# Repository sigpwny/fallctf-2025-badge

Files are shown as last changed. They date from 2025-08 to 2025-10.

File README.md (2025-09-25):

# FallCTF 2025 badge software and hardware

## Flags

Boot flag: `fallctf{s1gpwny_m4k3s_h4rdwar3!}`
game high score flag: `fallctf{w1z4rd_0f_st4rdust}`

## Software

See [board-setup/](board-setup/README.md) for flashing firmware on to the badge. See [dev/](dev/README.md) for the user code.

## Hardware

See [hardware/](hardware/README.md) for hardware design information.

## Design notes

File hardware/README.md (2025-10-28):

# Hardware

I recommend using Github's outline feature to navigate this document.

## Versioning

The PCB folder contains several versions of schematics. v0.1 through v0.3 were the prototype versions. v1.0 was used as the final badge design.

## Microcontroller

The badge has an ESP32-S2-SOLO-2-N4 module. This module features an ESP32-S2 SoC with 4MB of flash and internal antenna for 2.4Ghz Wi-Fi (no bluetooth).

The datasheet for the ESP32-S2-SOLO-2-N4 module is available [here](https://www.espressif.com/sites/default/files/documentation/esp32-s2-solo-2_esp32-s2-solo-2u_datasheet_en.pdf). See [here](https://www.espressif.com/sites/default/files/documentation/esp32-s2_datasheet_en.pdf) for the ESP32-S2 series documentation and [here](https://www.espressif.com/sites/default/files/documentation/esp32-s2_technical_reference_manual_en.pdf) for the ESP32-S2 technical reference manual.

### Boot modes

GPIO 46 (pin 16) is pulled low to avoid invalid configurations in boot pins. GPIO 0 (pin 27) is connected to the "B" pushbutton to allow switching between SPI (flash) boot and download (USB) boot. By default, it is pulled up, which selects SPI boot.

## Battery

The battery is a 400mAH 3.7V lithium-ion polymer battery.

## Peripherals

The FallCTF 2025 comes with a number of peripherals accessible from the ESP32 module via software. This is designed to be a comprehensive list for software developers working on the badge.

GPIO numbers are given for the ESP32 module. The relationship between pin numbers and IO port numbers are given in Table 3 on page 11 of the ESP32-S2-SOLO-2 datasheet.

### Overview

The following peripherals are available:
- USB (serial)
- two push buttons
- battery charge monitor
- SAO header
- buzzer
- joystick
- current sensor
- accelerometer
- display

### USB

USB D- is connected to GPIO 19 and D+ to GPIO 20 as required for "download boot", which is used to program the ESP32 over USB.

### Push buttons

"A" button is connected to GPIO 13 and "B" is connected to GPIO 0. Both buttons are pulled up by a 10K resistor and shorted to ground when depressed.

### Battery charge monitor

The battery is connected, through a pair of 100K resistors acting as a voltage divider, to GPIO 8. This allows for software to detect the battery charge via an ADC.

### SAO header

The SAO header shares an I2C connection with the accelerometer. SCL connected to GPIO 21 and SDA to GPIO 33. There are two SAO GPIO pins connected to GPIO 11 and GPIO 12.

### Buzzer

Both ends of the passive piezo buzzer are connected to the ESP32 through 220 Ohm resistors. One end is connected to GPIO 3 and the other to GPIO 9. We recommend grounding one of the pins and using the other as the PWM signal source.

### Joystick

The two axes of the joystick are connected to GPIO 4 and 5. The range is around from 0.8V to 1.4V. This varies by 2%-5% across devices.

The joystick has an internal variable resistance of 5K. One end is connected to an 8.2K resistor and the other end to a 820 Ohm resistor.

The exact part is [YTL YA13-FL7.4-B5Ka(45-10)-R-Y06](https://www.lcsc.com/datasheet/C37323742.pdf).

### Current sensor

There is a INA199A1DCKR ([datasheet](https://www.ti.com/lit/ds/symlink/ina199.pdf?ts=1758695550045)) connected to the 3.3V bus acting as a current sensor. It has a gain of 50 V/V. The output voltage is connected to GPIO 10. The current sensing resistor is 0.1 Ohms. To measure the operating current in Amps, use the formula `A = V / (I_R * G)`, where `A` is the operating current, `V` is the measured voltage in volts, `I_R` is the current sensing resistance (0.1 Ohms), and `G` is the gain (50 V/V).

From our testing, the current sensor is not very reliable and fluctuates wildly during use, reporting readings between 50% and 300%.

### Accelerometer

The STK8321 accelerometer ([datasheet](https://uploadcdn.oneyac.com/attachments/files/brand_pdf/sensortek/STK8321.pdf)) is attached to the same I2C lines as the SAO header (GPIO 21 and GPIO 33). The accelerometer's two interrupt pins are connected to GPIO 37 and GPIO 38. The slave address select pin is connected to GPIO 36. By default, this pin is pulled low, which selects the I2C address 0x0F. The chip supports a max I2C frequency of 400kHz.

Example initialization process:
- write 0xB6 to 0x14 (SWRST) to reset the chip
- write 0x03 to 0x0F (RANGESEL) to set the range to +/- 2g (this can be changed to 0x05 for +/- 4g or 0x08 for +/- 8g)
- write 0x0B to 0x10 (BWSEL) to set the bandwidth to 62.5Hz (this can be changed for different bandwidths)

For an example of code used to drive the accelerometer, see dev/accelerometer.py

### Display

The display is a 1.8" 128x160 color TFT LCD display with a ST7735S controller, sourced [from BuyDisplay](https://www.buydisplay.com/128x160-1-8-inch-color-tft-lcd-display-with-st7735-controller-spi). The controller datasheet is available [here](https://www.buydisplay.com/download/ic/ST7735S.pdf).

The following pins are connected:
- CS: GPIO 17
- RESET: GPIO 18
- DC: GPIO 7
- MOSI: GPIO 16
- SCK: GPIO 15
- LCD_LED: GPIO 41

The CS (chip select) and RESET pins are pulled high by default by the PCB. The DC and MOSI pins allow data and commands to be transmitted to the display controller. The SCK determines the clock speed. The datasheet specifies a max clock speed of 15Mhz, but we have found through testing that it supports a clock rate as high as 90Mhz (although values above 61Mhz do not appear to have any differences). In the final badge design, we used 40Mhz.

The LCD_LED pin is connected to a MOSFET which switches the backlight on and off. This pin can be driven with PWM to adjust the brightness of the backlight. We have found that a duty cycle between 20% and 40% offers a good visual experience.

## Prototype pictures

### v0.1

TODO: add pictures

### v0.2

TODO: add pictures

### v0.3

TODO: add pictures

### v1.0

TODO: add pictures

## Design process and challenges

### Lessons learned

Here are some of the most important lessons I learned during the hardware design process:
- Use a circuit simulator (such as [falstad](https://www.falstad.com/circuit/circuitjs.html)). This is great especially if you don't have a solid grasp of basic electronics (like me at the start of this project). This allows you to catch basic mistakes such as flipped MOSFETs or incorrect resistor values.
- Design PCBs with plenty of room. In the prototyping stage, there's no need to squeeze everything together. Space out the traces to make reworking easier. This also makes it easier to debug and test the board.
- Order small batches. I ordered 10-15 boards at a time, which was unnecessary and wasteful. Ordering 5 boards at a time is sufficient for prototyping.

### Electrical problems

- USB shell
    - In v0.1, I connected the shell to ground through a 1M resistor. This was a mistake and removed in v0.2. The shell should be connected directly to ground.
- current limits
    - In v0.3, the LDO was only rated for 300mA, which is not enough to power the ESP32 at full Wi-Fi power. This was fixed in v1.0 by using a 500mA LDO.
- MOSFET direction
    - In v0.1, I was using the P-channel MOSFET in the wrong direction (swapped source and drain). This was fixed in v0.2, although this iteration had other problems (see below).
- MOSFET body diode
    - In v0.3, the body diode on the Q1 MOSFET allowed the 5V to inadvertently flow back to the battery, charging it. This was a problem as this spiked the current drawn from the USB port, causing it to shut off. This was fixed in v1.0 by using a second MOSFET (Q5). I made this mistake because I forgot about the body diode in a MOSFET and mistakenly believed that tying gate and source together would turn it off even if the drain was at a higher voltage than the source.
- swapped display backlight pins
    - In v0.2, I swapped the anode and cathode of the backlight LED. This was fixed in v0.3.

### Physical layout

- ESP32 module does not need to stick out of the board. This was recommended by the design, but some testing revealed that the antenna performance was not significantly affected by being surrounded by PCB material. The protruding design makes the badge more fragile and prone to damage.
- Switches not stick out too far from the edge of the board. Sometimes the 3D model can be misleading. Always check the physical size with the datasheet.
- In general, confirm the physical size of large parts to make sure they do not interfere with each other

### Part selection

Here is my general process for part selection:
- Choose parts that are commonly used and have good documentation. Avoid obscure parts that may be hard to source or have poor documentation.
- Prefer JLCPCB's basic parts, as they incur lower production costs.
- If there is a part you like that is too expensive, look for alternatives with the same specifications on multiple websites. Generally, most parts have "generic" versions that are significantly cheaper.

### JLCPCB PCBA capabilities

Keep in mind manufacturer's PCBA capabilities when designing the PCB, specifically when setting up the design rules. See [JLCPCB's capabilities](https://jlcpcb.com/capabilities/pcb-capabilities). In particular, the page on [extra fees](https://jlcpcb.com/help/article/in-what-cases-will-there-be-charged-extra) states that the via inner hole size must be at least 0.3mm and the via outer diameter must be at least 0.4mm to qualify for no extra fees (note: the via hole size can be at least 0.2mm if the via diameter is at least 0.45mm).

### Lanyards

Lanyards weren't ordered in time for the competition. We ordered it the Monday before the competition (6 days prior), which was way too late. In future, we should order lanyards at least 3 weeks in advance.

### Lack of RAM

This is more of a software problem, but the underlying cause was hardware. We kept running out of RAM, as micropython by itself is very RAM-hungry. On top of that, the ESP Wi-Fi stack requires significant amount of memory as well. Adding to the problem is the fact that micropython runs as a task in ESP-IDF (which is based on FreeRTOS). This means that the micropython heap is separate from ESP-IDF's heap, and memory fragmentation can occur in both heaps. The solution was to freeze as much code as possible into the firmware, which reduces the amount of RAM needed at runtime. However, in future designs, we could use one of the ESP32 modules with embedded PSRAM (or even use a ESP32 SoC directly with external PSRAM).

### Improvements for future designs

- Separate user controllable (blue?) LED. No need for a power LED.
- Increase joystick voltage divider R39 and R40 to around 10K

### Software is hard

My biggest advice regarding software is to start earlier. I would recommend starting in early spring. The idea should be concretized by the end of spring so that work can begin over the summer. I think one of the biggest issues with the FallCTF 2025 badge was that the main software idea was not finalized until August, which left very little time for development and testing.

## Final hardware design

### ESP32 module

Most of the design is pretty straightforward. There wasn't anything here that significantly differed from the recommended design in the datasheet.

### USB

We use several diodes for surge and ESD protection on the USB data and power lines. CC1 and CC2 are connected to ground through 5.1K resistors to indicate to the host that this is a USB 2.0 device, which allows it to draw up to 500mA from the host. The shell is connected directly to ground.

### Power regulation

This was by far the most complicated part of the design. The design went through several iterations before arriving at the current version, which uses two P-channel MOSFETs to switch between USB power and battery power. Notice that the Q1 MOSFET in the v1.0 schematic is actually "flipped" upside down: the source is at the bottom and the drain is at the top. There are three cases to consider:

- When both the USB and battery are connected. The 5V on the USB line causes the gate and source of Q1 to be at the same voltage (minus a small drop from the Schottky diode), so Q1 is turned off. This prevents current from flowing back to the battery, as there is separate dedicated circuitry to charge the battery. The 5V flows downstream to the LDO to power the rest of the badge.
- When only the USB is connected. The same logic as above applies, and the badge is powered from the USB line.
- When only the battery is connected. This is where it gets interesting. Depending on the state of SW1, the gate of Q5 is either tied to ground or to VBAT. If it is tied to ground, then Q5 is turned off and no current can flow past it. If it is tied to VBAT (which is also Q5's source), then Q5 is turned on and current can flow through Q5. From there, the current flows through the body diode of Q1 (which is oriented in the correct direction to allow current flow) and into the LDO to power the badge. The Schottky diode (D4) prevents current from flowing back to the USB line.

The Schottky diode can be used because the drop from 5V to 3.3V is large enough that the small drop across the diode (typically around 0.3V) does not matter. The resistors on the gate of each MOSFET are to prevent inrush current from damaging the MOSFET (I'm not sure if this is actually necessary, but it doesn't hurt). The pull-down resistor R2 is not necessary and is a remnant from an earlier design iteration.

The ME6211C33M5G 3.3V LDO I chose can handle up to 500mA of current, which is the recommended amount for the ESP32. In previous iterations, the LDO could only handle 300mA, which was not enough to power the badge when transmitting at full Wi-Fi power.

### Power indicator LED

Tuning the resistor on this LED was surprisingly tricky. I went from 680 -> 8.2K -> 13K. If the [datasheet](https://www.lcsc.com/datasheet/C2297.pdf) is to be trusted, the 13K resistor should result in a current of around 75uA, which is extremly dim (less than 2% of the intensity at 5mA, which is between 175 and 430 mcd with a 120 degree viewing angle).

### Battery charging

I used the TP4054 ([datasheet](https://media.digikey.com/pdf/Data%20Sheets/UTD%20Semi%20PDFs/TP4054.pdf)) for battery charge control. I used a 4.7K resistor to program the max charging current to 200mA, but that may have been too conservative. A better approach would be to allow the MCU to program this value (even something as simple as selecting between a "fast" and "slow" charge would have been better). There is some slightly more complicated circuitry to control the green and red charging LEDs, but those are straight from the datasheet. The resistor values have been tuned to reduce the brightness (since the LEDs are quite efficient).

### Buttons

Nothing special here. Standard 10K pull-up resistors.

### Joystick

Connected the joystick in series with a 8.2K on one side and a 820 Ohm resistor on the other side to offset the voltage divider so it sits nicely within the ESP32's ADC range (2.5V). This could have been improved by increasing the resistance slightly so that it fits in the `ADC_ATTEN_DB_6` range (which is 0V-1.3V). Currently the max is around 1.4V, which is slightly out of this narrower range.

### Accelerometer

Recommended design from the datasheet. Connecting the interrupts to the ESP32 was a nice feature, but unused.

### Current sensing

Fluctuates wildly. I'm not sure if the actual current is really so unstable or if I could have chose a better sensing resistor or amplifier.

### Buzzer

I connected both ends to the ESP32 through 220 Ohm resistors for greater flexibility in control. This allows the buzzer to be driven in a push-pull configuration, which would be twice as loud as driving it in a single-ended configuration. However, the buzzer is quite loud even when driven in a single-ended configuration, so this was unnecessary.

### Display

Besides connecting a N-channel MOSFET to be able to vary the backlight, everything else was straight from the datasheet.

## Costs

Here are the main costs associated with developing the badge for FallCTF 2025. We ended up ordering 300 badges in the final order.

- prototypes
    - over three revisions of prototypes, we spent: $709.52
    - 3.76 + 60.00 + 73.99 + 43.68 + 20.88 + 16.30 + 162.02 + 26.74 + 56.96 + 5.98 + 180.66 + 17.45 + 41.10
- PCBA
    - total: $1782.33
    - includes $70.02 part preorder
    - cost breakdown:
        - MERCHANDISE TOTAL: $900.81
        - SHIPPING CHARGE: $226.86
        - Customs duties & taxes: $525.72
        - DISCOUNT: -$15.00
        - SALES TAX: $73.92
        - ORDER TOTAL: $1712.31
    - pcb cost: $173.10
    - assembly cost: $727.71 ($366.59 for components)
        - does not include ESP32, which we got for free
- other final badge parts
    - batteries: $453.88
        - supplier: [General Electronics Technology Co., Ltd.](https://geb.en.alibaba.com/index.html?spm=a2700.details.0.0.346c748eiMNOtQ&from=detail&productId=1600518355723)
    - displays: $1008.65 (including $281.56 duty)
- lanyards: $253
- badge cases: $260 (3d printed in our school's print farm)
 
Total costs: $4600

## Gallery

### PCB prototypes

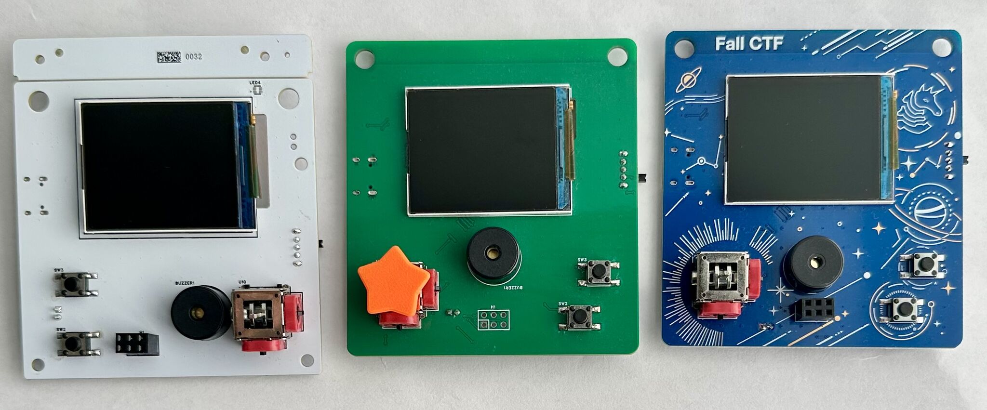
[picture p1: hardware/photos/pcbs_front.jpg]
The front of three prototype boards


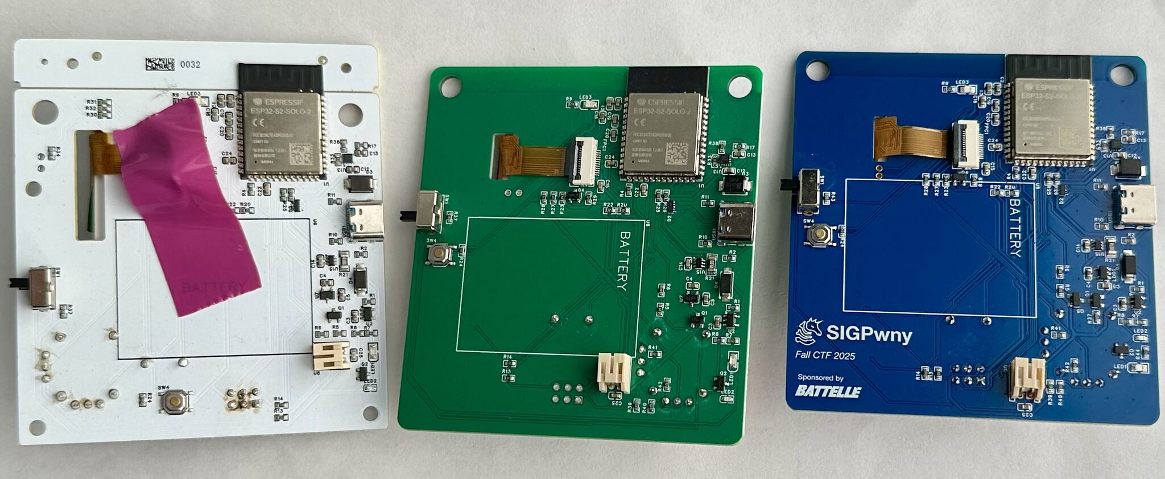
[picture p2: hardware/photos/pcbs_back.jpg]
The back of three prototype boards


### Case prototypes

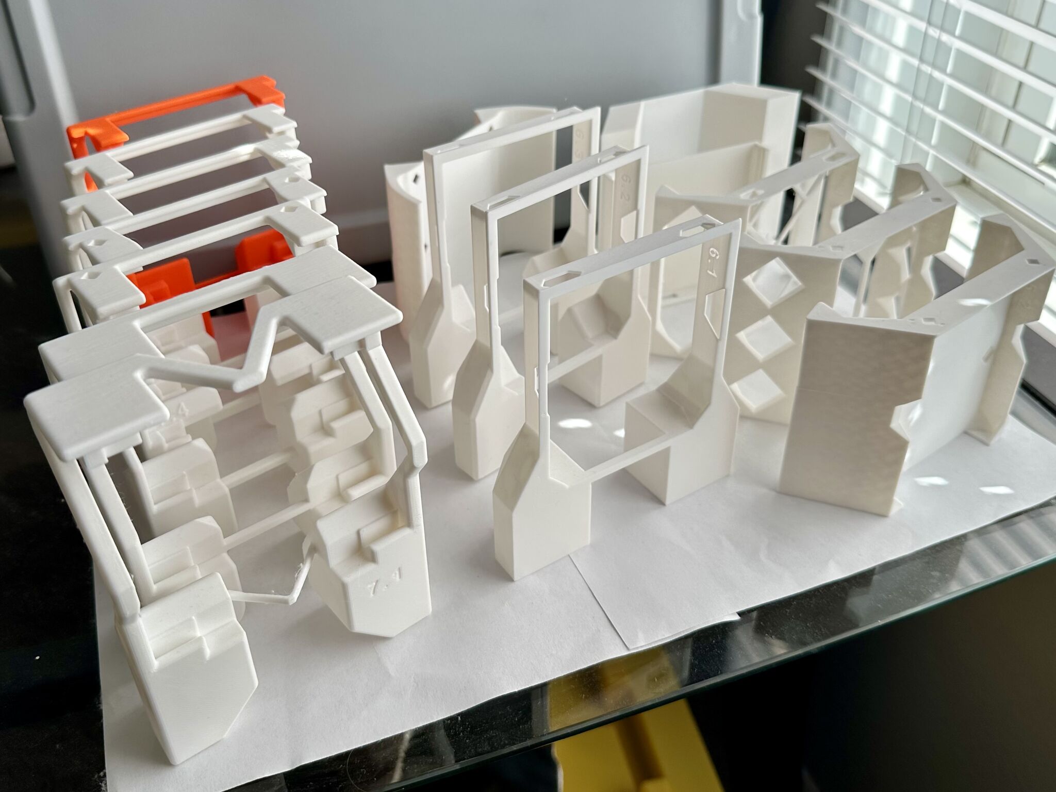
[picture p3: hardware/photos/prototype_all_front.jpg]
Front view of more than a dozen 3D printed prototype cases


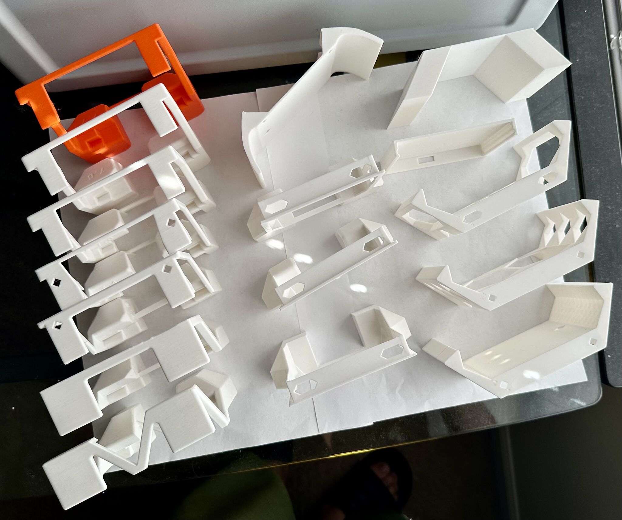
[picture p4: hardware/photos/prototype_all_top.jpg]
Top view of more than a dozen 3D printed prototype cases


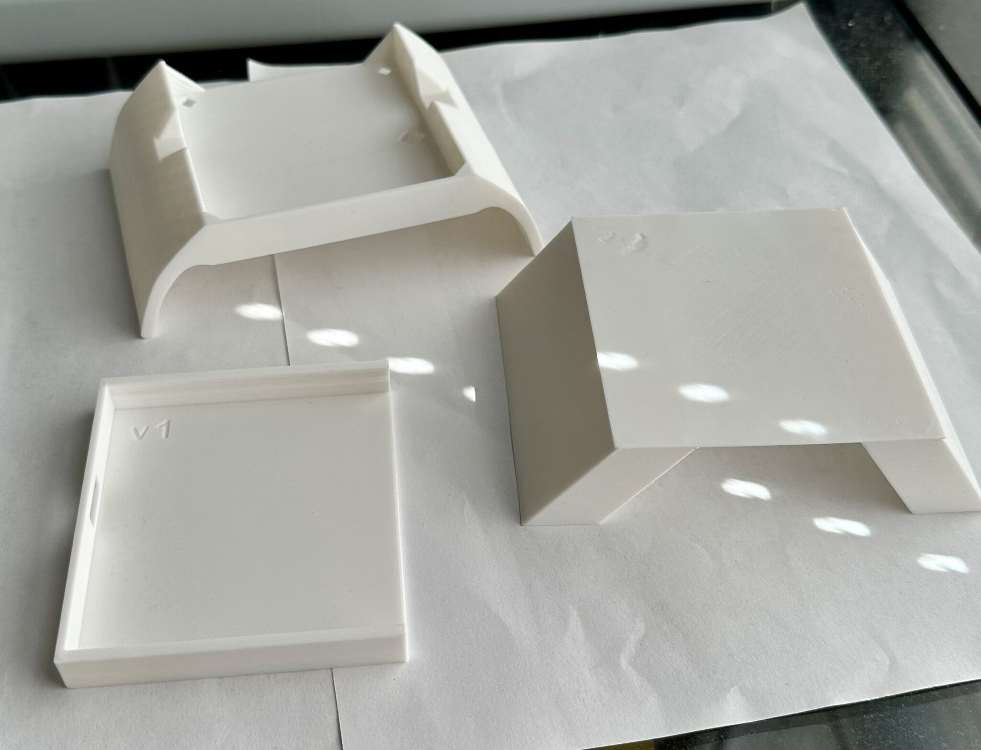
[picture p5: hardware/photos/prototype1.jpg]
Three early stage prototypes, simple geometric shapes


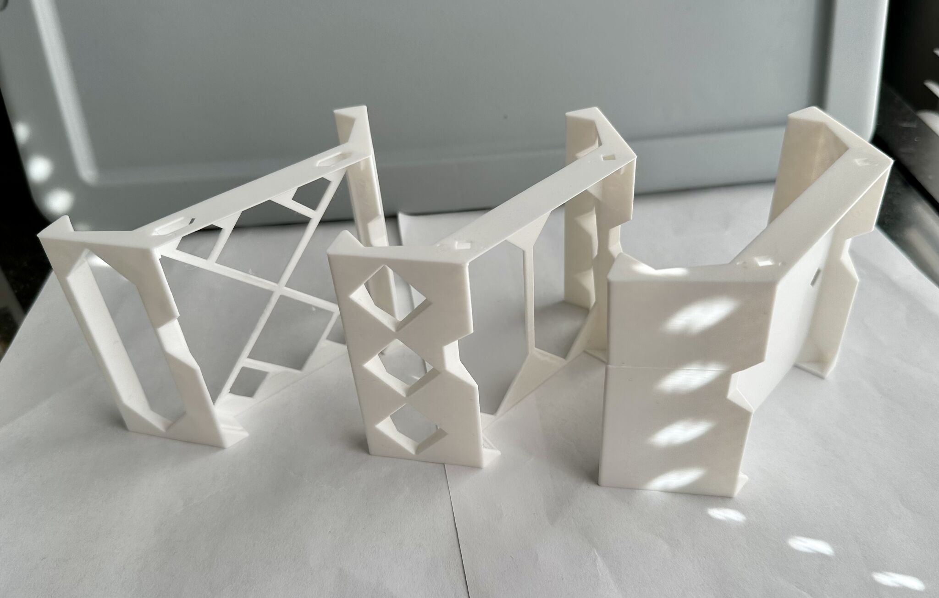
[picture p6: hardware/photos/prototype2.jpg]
Three more prototypes with more holes for cost reduction


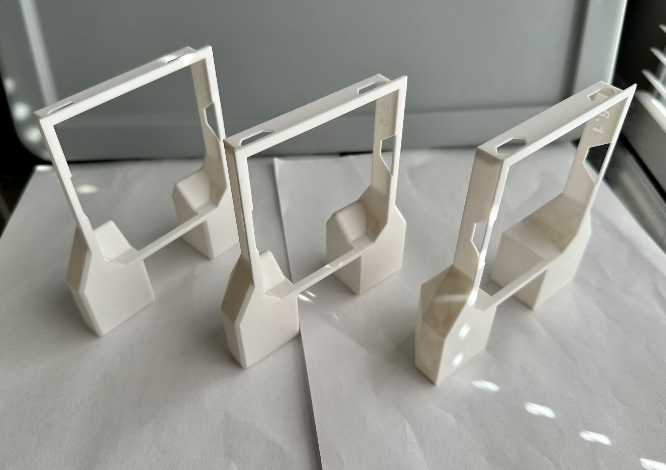
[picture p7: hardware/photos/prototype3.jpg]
Three more prototypes with handles for easier grip


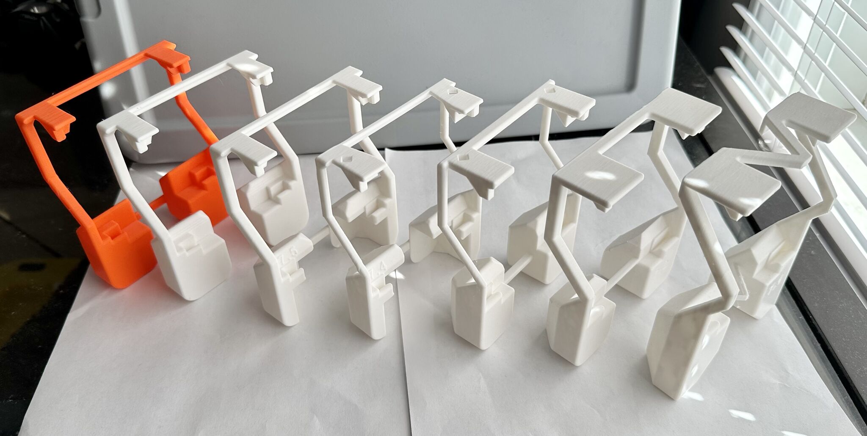
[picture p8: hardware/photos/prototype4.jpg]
Final series of seven prototypes with overall boxy look


### Final badge

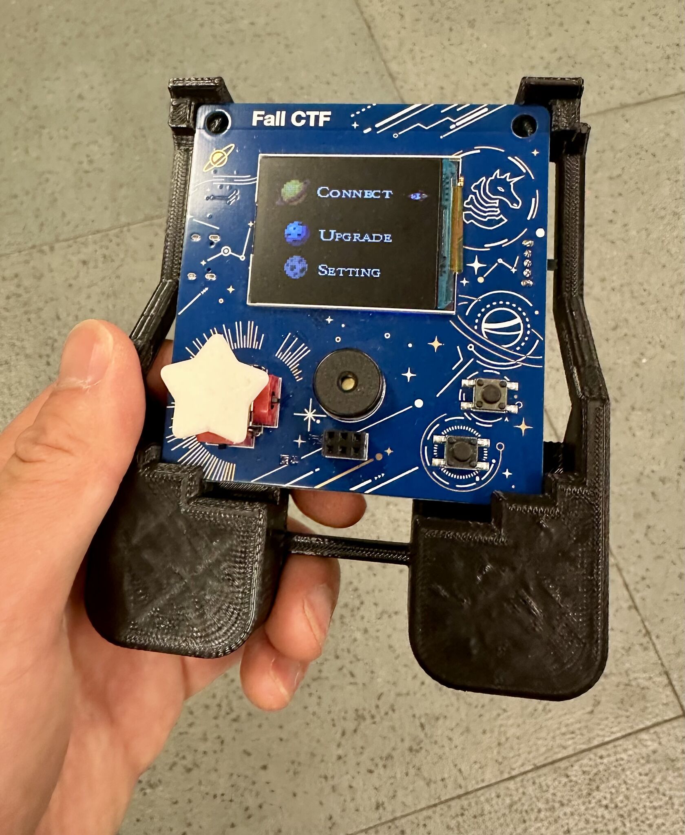
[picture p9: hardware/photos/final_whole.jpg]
Final badge


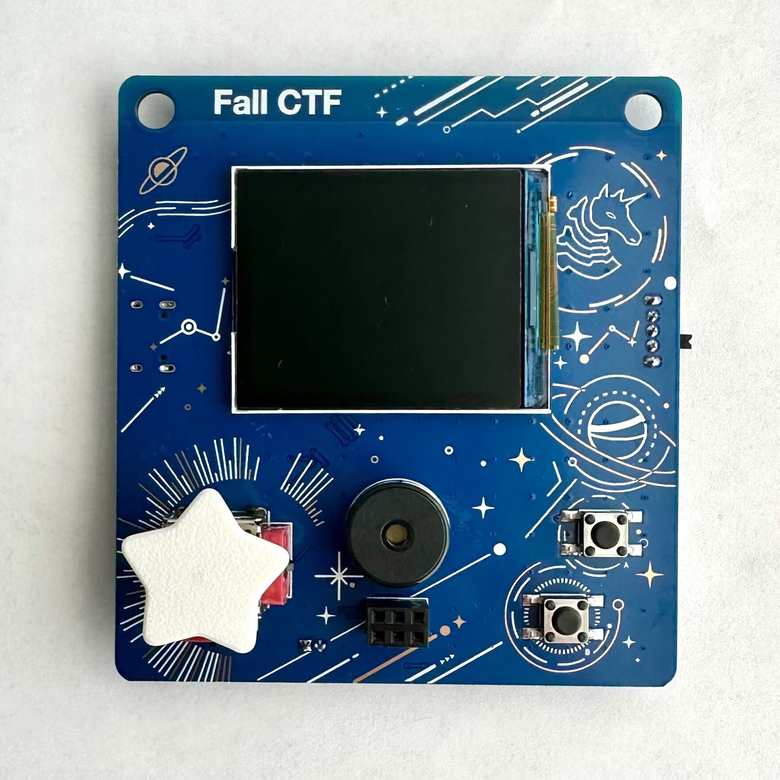
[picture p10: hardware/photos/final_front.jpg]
Front of badge


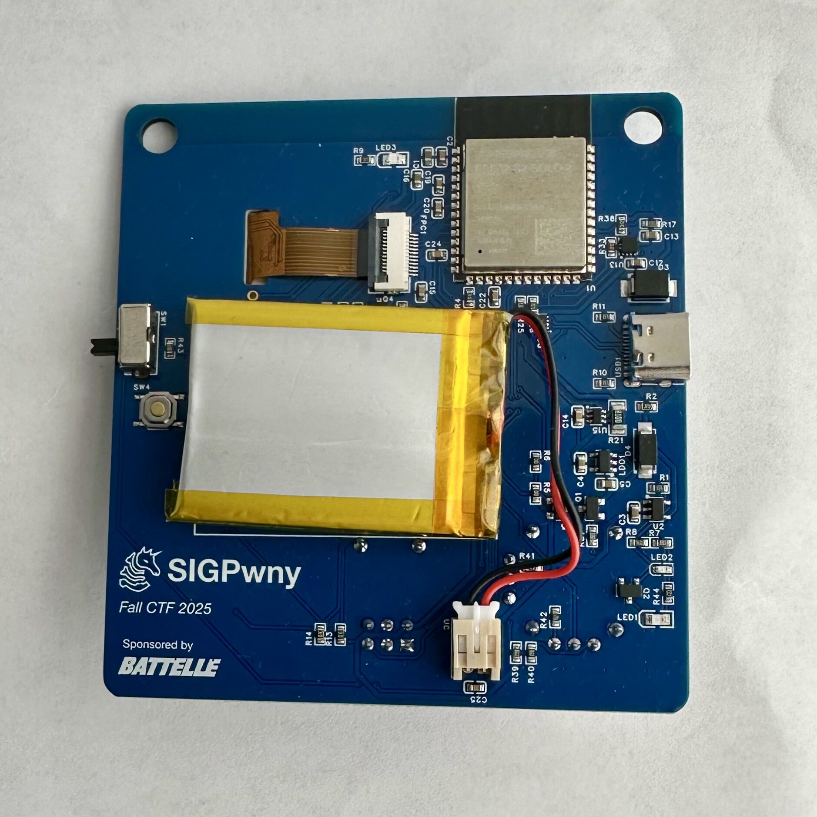
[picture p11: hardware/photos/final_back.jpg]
Back of badge


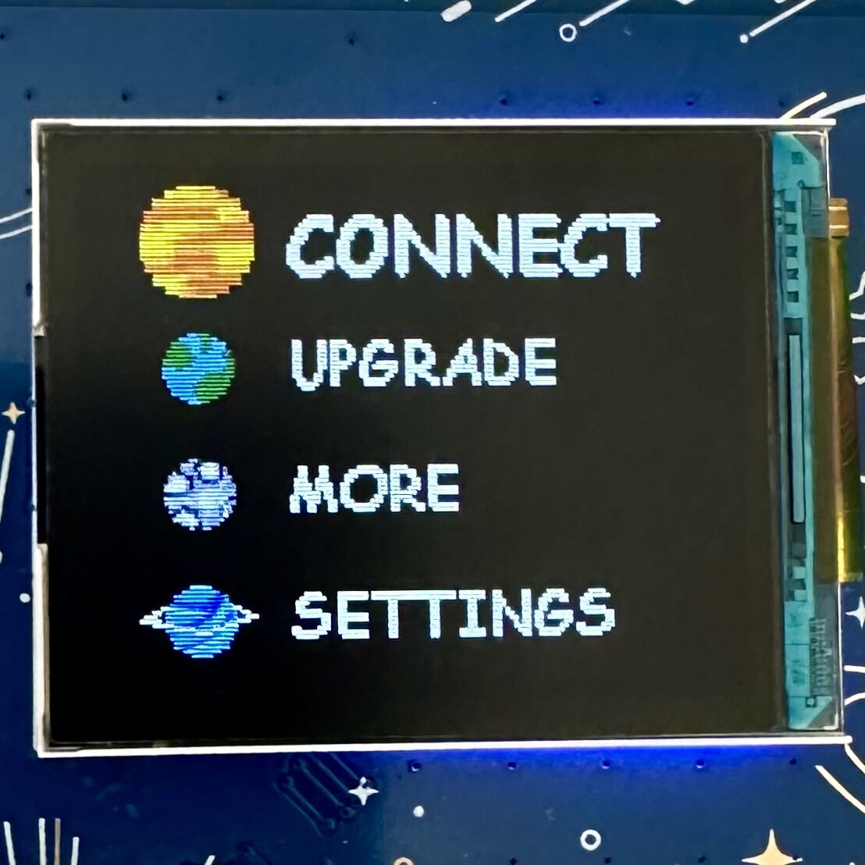
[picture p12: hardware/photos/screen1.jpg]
Menu screen


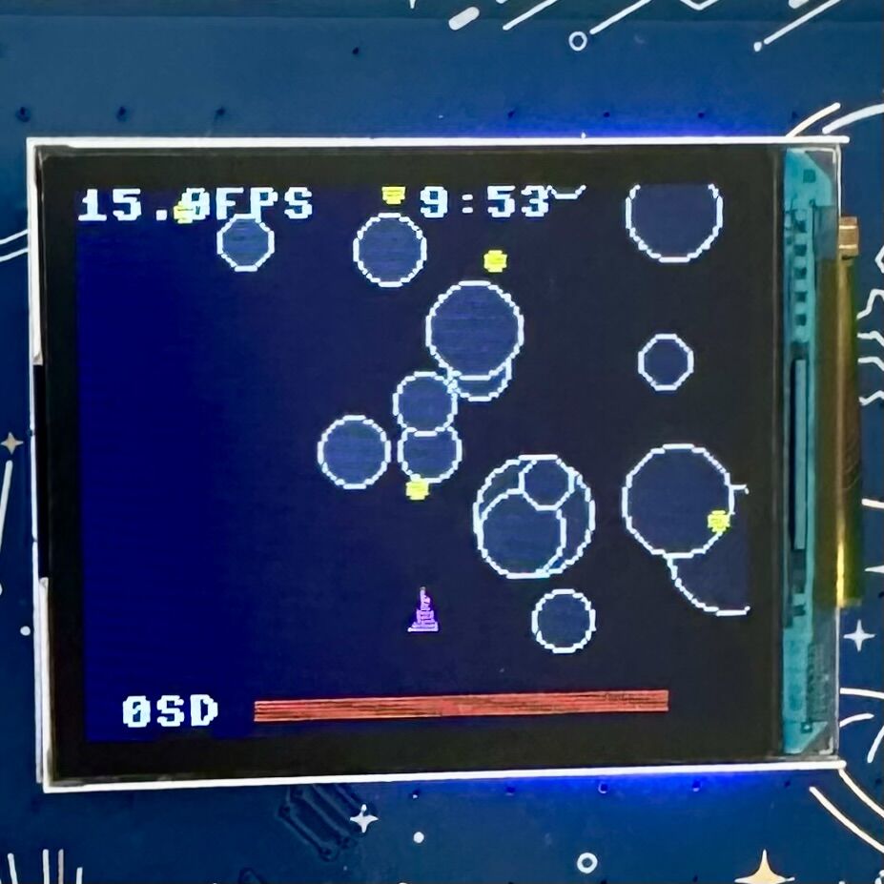
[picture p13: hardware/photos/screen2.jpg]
Asteroids game screen


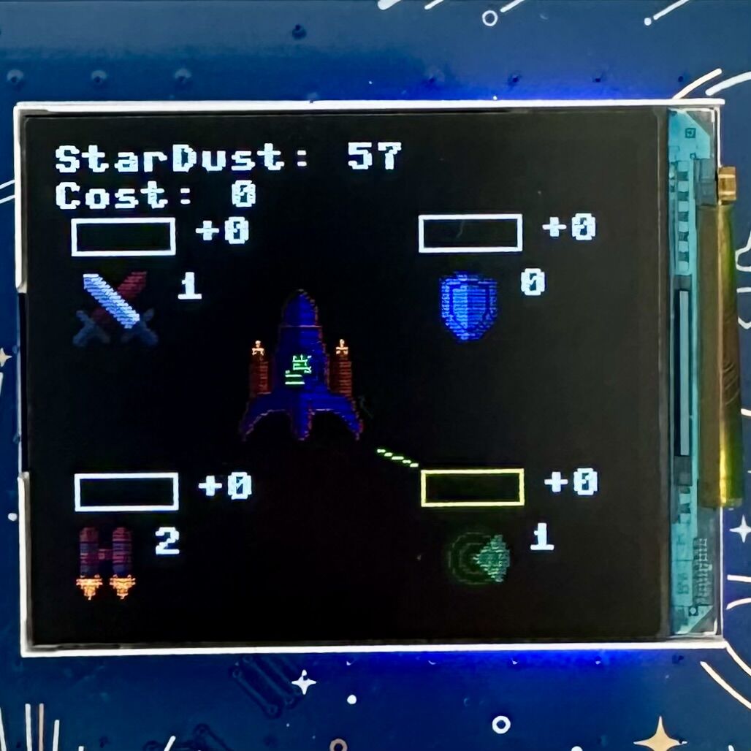
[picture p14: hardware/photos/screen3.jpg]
Upgrades screen


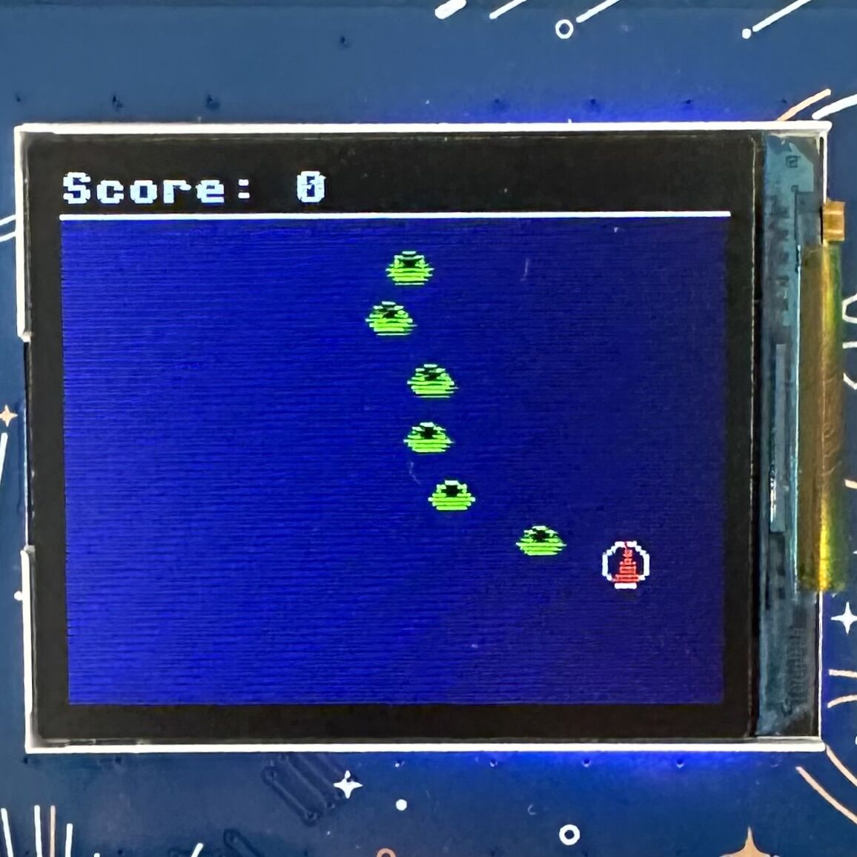
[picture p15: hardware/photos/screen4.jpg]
Space invaders game screen


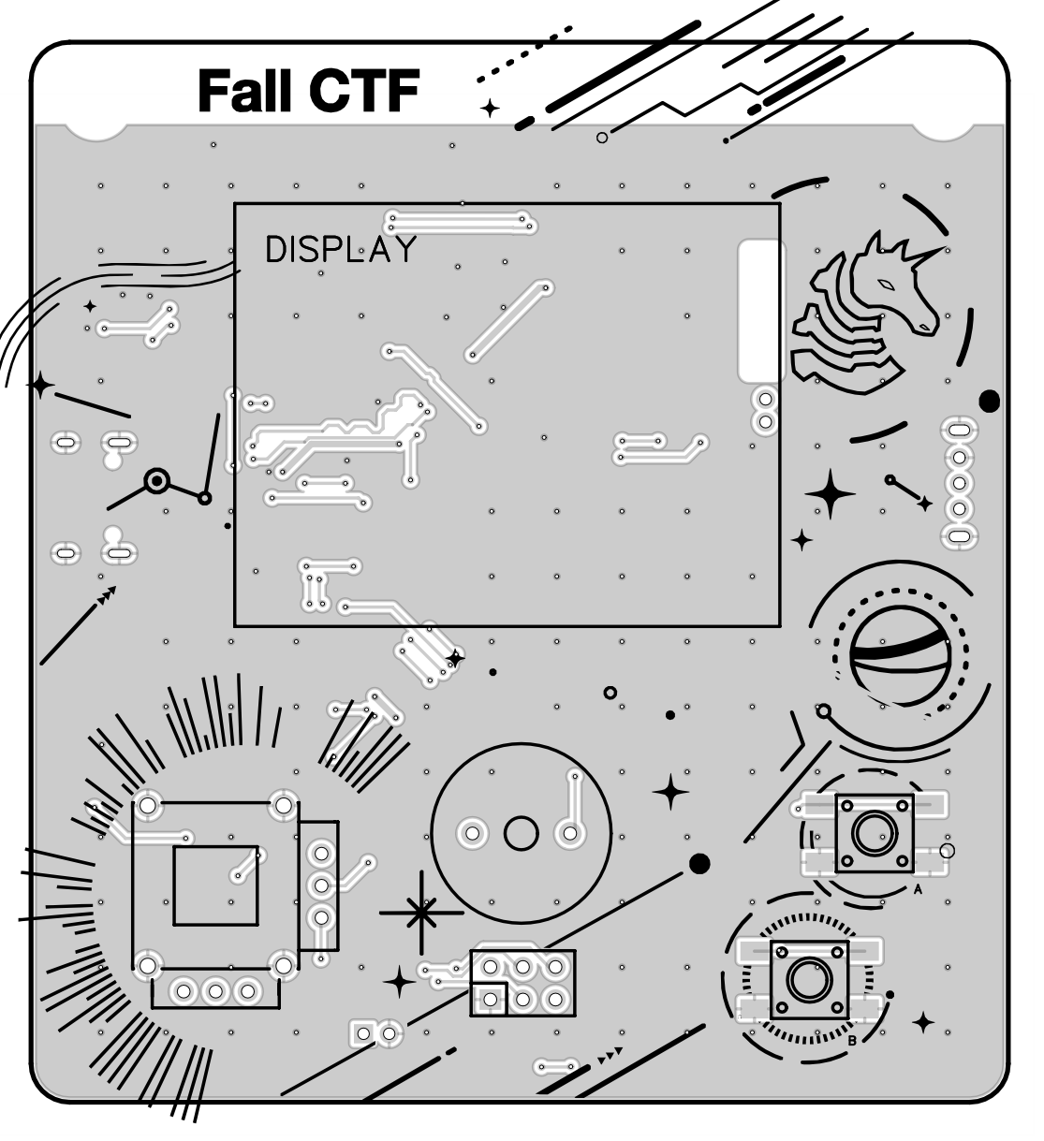
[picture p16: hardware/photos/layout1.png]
PCB layout front


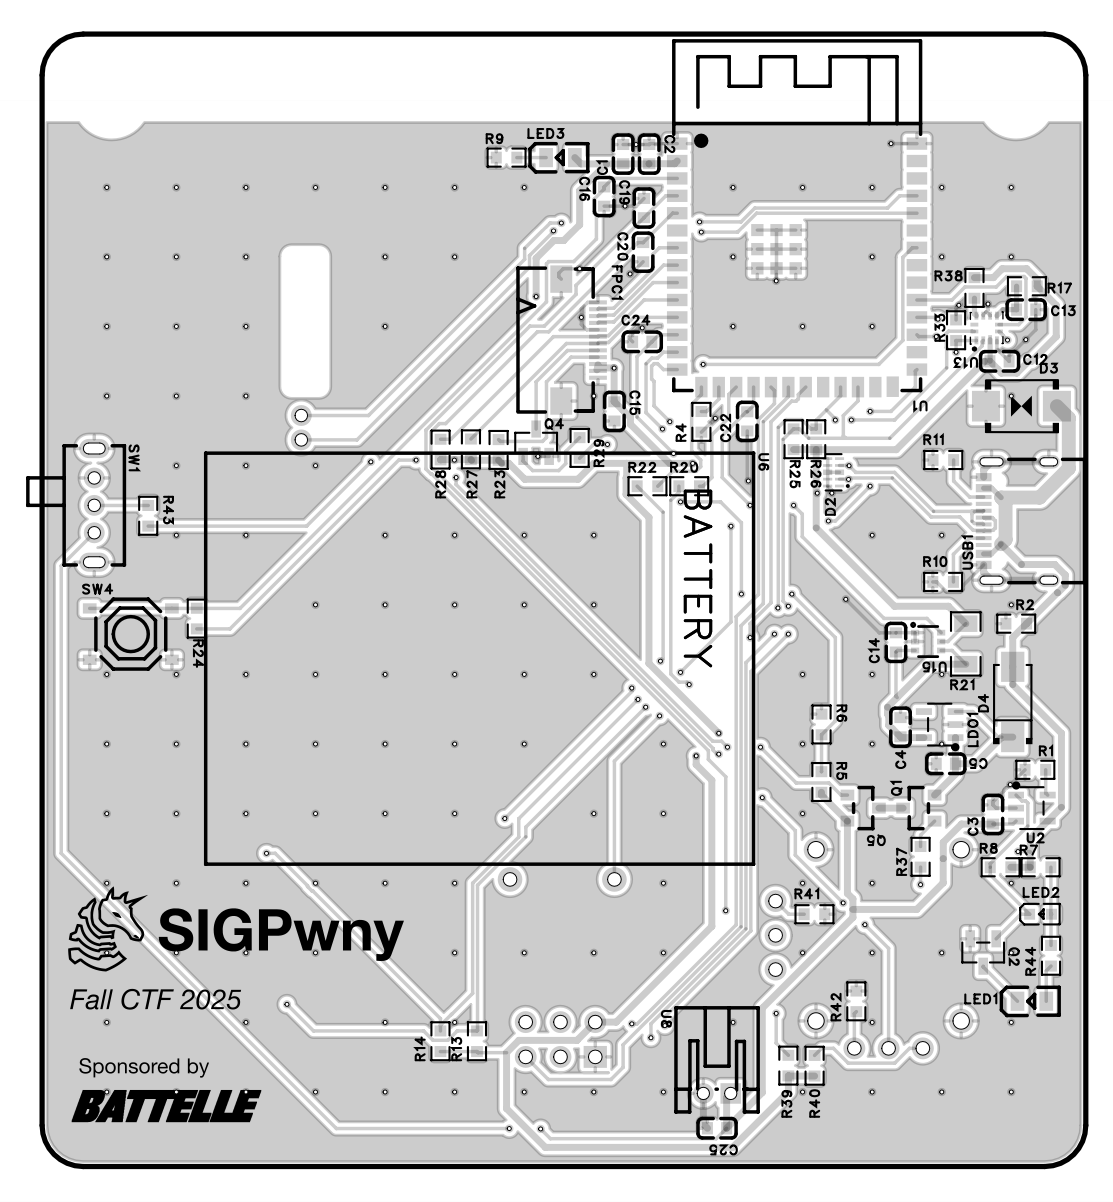
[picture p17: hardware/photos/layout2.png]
PCB layout back


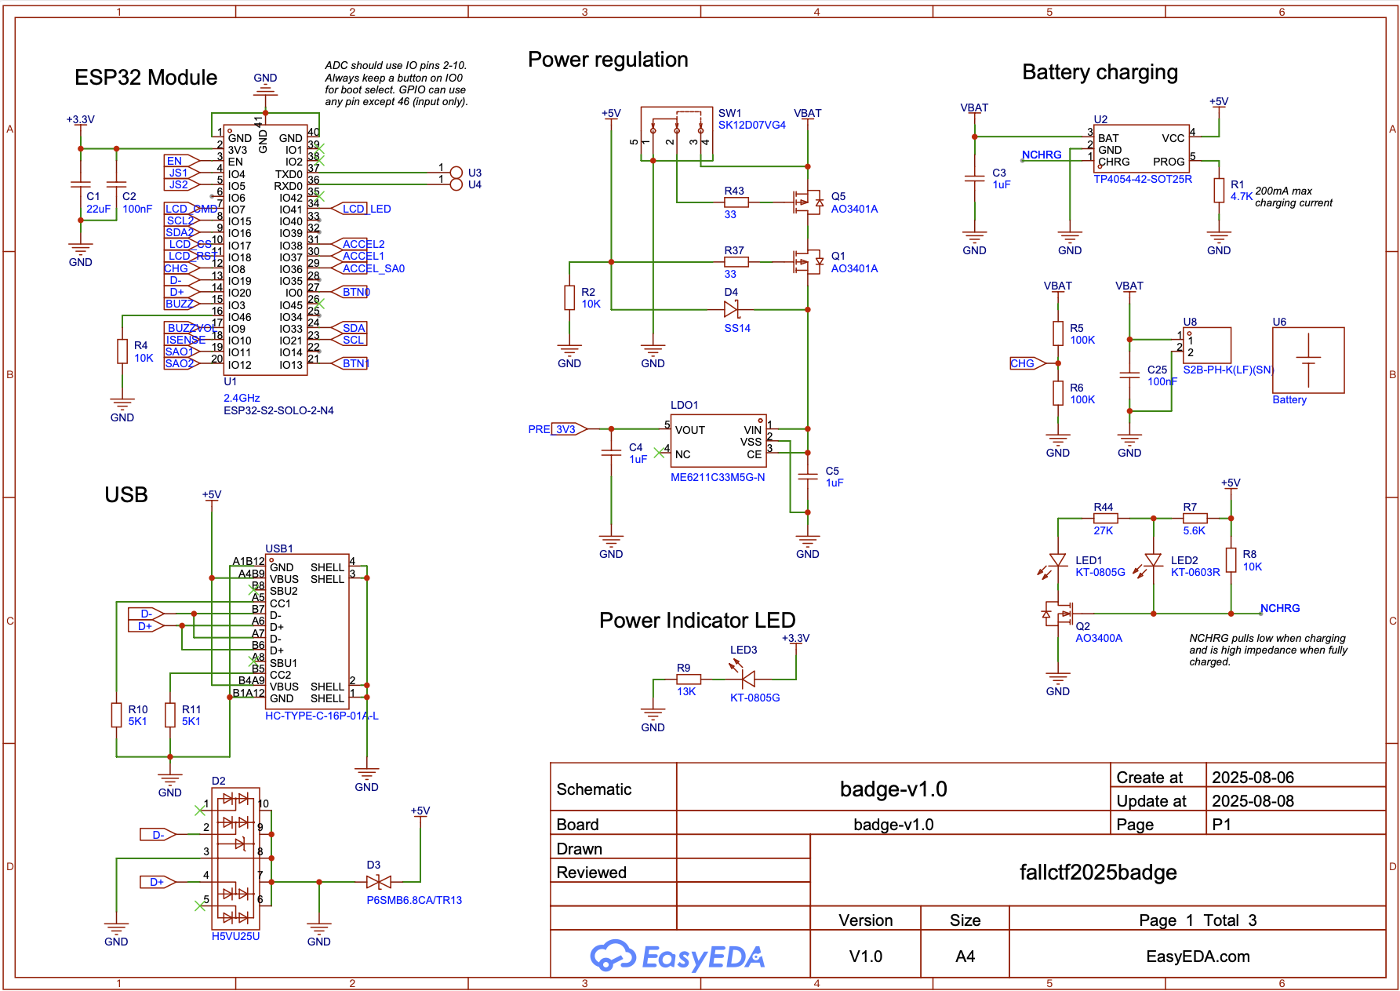
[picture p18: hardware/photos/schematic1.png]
PCB schematic first page


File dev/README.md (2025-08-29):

# Badge software architecture

## Overview

The main architecture is cooperative multitasking with asyncio.

Tasks (may not be comprehensive):
- Display: draws to screen
- MainController: handles main menu interaction
- Wireless: handles ESP-Now communication
- Settings: manages defaults and user-adjustable settings
- GamePlay: manages gameplay
- peripheral tasks:
    - Joystick
    - PushButtons
    - Accelerometer
    - Buzzer
    
The `View` object is used by the MainController to communicate to the Display what to show on the screen.

Example flow:
> User moves the joystick down, which scrolls to the next menu item"
- joystick task detects motion
    - waits until enough motion triggers a "down" detection
    - publishes messages
- MainController task receives message (already subscribed to it from the start)
  - updates internal model of selection to move down
  - calls Display with new updated View

Another example flow:
> User pushes button to select an upgrade item
- button detections motion and publishes msg
- MainController (sub'ed) receives msg
    - tells GamePlay to update with the upgrade data
    - then updates Display with new View

The tasks are all bundled together in an `Environment`. There are two Environments currently (dev and test). The test environment does not have access to peripherals, wireless, and screens. Those classes will be simulated instead. This is to test the core functionality.

Instead of using `print` debugging, please use the internal `log` method.

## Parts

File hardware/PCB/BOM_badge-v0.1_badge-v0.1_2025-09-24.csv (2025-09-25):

No. | Quantity | Comment | Designator | Footprint | Value | Manufacturer Part | Manufacturer | Supplier Part | Supplier
1 | 1 | 4kHz | BUZZER1 | BUZ-TH_BD12.5-P5.00-D0.9 | 4kHz | PS1240P02CT3 | TDK | C76873 | LCSC
2 | 1 | 22uF | C1 | C0603 | 22uF
3 | 1 | 100nF | C2 | C0603 | 100nF
4 | 1 | 4.7uF | C3 | C0603 | 4.7uF
5 | 3 | 10uF | C4,C5,C6 | C0603 | 10uF
6 | 1 | 1uF | C7 | C0603 | 1uF
7 | 1 | S2B-XH-A-1(LF)(SN) | CN1 | CONN-TH_S2B-XH-A-1-LF-SN |  | S2B-XH-A-1(LF)(SN) | JST | C163035 | LCSC
8 | 1 | 1N5819WS | D1 | SOD-323_L1.7-W1.3-LS2.5-RD |  | 1N5819WS | KEXIN(科信) | C369937 | LCSC
9 | 1 | USBLC6-2SC6 | D2 | SOT-23-6_L2.9-W1.6-P0.95-LS2.8-BL |  | USBLC6-2SC6 | GOODWORK(固得沃克) | C21713975 | LCSC
10 | 1 | 2.54-1*4P母 | H1 | HDR-TH_4P-P2.54-V-F |  | 2.54-1*4P母 | BOOMELE(博穆精密) | C2718488 | LCSC
11 | 1 | PM2.54-2*3 | H2 | HDR-TH_6P-P2.54-V-F-R2-C3-S2.54 |  | PM2.54-2*3 | ZHOURI(洲日) | C5116527 | LCSC
12 | 1 | D-060306R1/SS2/L | LED1 | LED0603-RD |  | D-060306R1/SS2/L | ARKLED(方舟) | C118330 | LCSC
13 | 1 | SSM3J338R,LF | Q1 | SOT-23F_L2.9-W1.8-P0.95-LS2.4-BR |  | SSM3J338R,LF | TOSHIBA(东芝) | C146352 | LCSC
14 | 1 | 300 | R1 | R0603 | 300
15 | 1 | 3.3K | R2 | R0603 | 3.3K
16 | 9 | 10K | R3,R4,R7,R11,R12,R13,R14,R15,R16 | R0603 | 10K
17 | 2 | 100K | R5,R6 | R0603 | 100K
18 | 2 | 5K1 | R8,R9 | R0603 | 5K1
19 | 1 | 1M1 | R10 | R0603 | 1M1
20 | 2 | 4K7 | R17,R18 | R0603 | 4K7
21 | 7 | TS-1102S-C-C-B | SW1,SW2,SW3,SW4,SW5,SW6,SW7 | KEY-SMD_4P-L6.0-W6.0-P4.50-LS8.6 |  | TS-1102S-C-C-B | XKB Connectivity(中国星坤) | C381039 | LCSC
22 | 4 | Test-Point | TP1,TP2,TP3,TP4 | Test-Point-0.5mm
23 | 1 | 2.4GHz | U1 | WIRELM-SMD_ESP32-S3-WROOM-1 | 2.4GHz | ESP32-S2-SOLO-2-N4 | ESPRESSIF(乐鑫) | C3040594 | LCSC
24 | 1 | TP4054 | U2 | TSOT-23-5_L2.9-W1.6-P0.95-LS2.8-BR |  | TP4054 | UMW(友台半导体) | C668215 | LCSC
25 | 1 | XC6220B331MR | U3 | SOT-23-5_L2.9-W1.6-P0.95-LS2.8-BR |  | XC6220B331MR | TECH PUBLIC(台舟) | C3040644 | LCSC
26 | 1 | SSD1315 | U4 | OLED-TH_L27.8-W27.2-P2.54_C9900033791 |  | HS96L03W2C03 | HS(汉昇) | C5248080 | LCSC
27 | 1 | ZX-PZ2.54-2-5PZZ | U5 | HDR-TH_10P-P2.54-V-M-R2-C5-S2.54 |  | ZX-PZ2.54-2-5PZZ | Megastar(兆星) | C7501276 | LCSC
28 | 1 | HC-TYPE-C-16P-01A-L | USB1 | USB-C-SMD_G-SWITCH_GT-USB-7010EN |  | HC-TYPE-C-16P-01A-L | HCTL(华灿天禄) | C2997432 | LCSC

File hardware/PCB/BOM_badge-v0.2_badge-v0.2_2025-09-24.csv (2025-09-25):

No. | Quantity | Comment | Designator | Footprint | Value | Manufacturer Part | Manufacturer | Supplier Part | Supplier
1 | 1 | 4kHz | BUZZER1 | BUZ-TH_BD14.0-P7.60-D0.7 | 4kHz | SFN-1407PA7.6 | S&S(海旭) | C360603 | LCSC
2 | 1 | 22uF | C1 | C0603 | 22uF
3 | 8 | 100nF | C2,C14,C15,C19,C20,C22,C24,C25 | C0603 | 100nF
4 | 6 | 1uF | C3,C4,C5,C12,C13,C16 | C0603 | 1uF
5 | 1 | H5VU25U | D2 | DFN2510-10_L2.5-W1.0-P0.50-BL |  | H5VU25U | 宏迦橙 | C7420374 | LCSC
6 | 1 | P6SMB6.8CA/TR13 | D3 | SMB_L4.6-W3.6-LS5.3-BI |  | P6SMB6.8CA/TR13 | Brightking(君耀电子) | C78395 | LCSC
7 | 1 | SS14 | D4 | SMA_L4.2-W2.6-LS5.3-RD |  | SS14 | MDD(辰达半导体) | C2480 | LCSC
8 | 1 | AFC01-S12FCA-00 | FPC1 | FPC-SMD_AFC01-S12FCA-00 |  | AFC01-S12FCA-00 | JS(钜硕电子) | C262661 | LCSC
9 | 1 | PM2.54-2*3 | H1 | HDR-TH_6P-P2.54-V-F-R2-C3-S2.54 |  | PM2.54-2*3 | ZHOURI(洲日) | C5116527 | LCSC
10 | 2 | KT-0805G | LED1,LED3 | LED0805-R-RD |  | KT-0805G | KENTO | C2297 | LCSC
11 | 1 | KT-0603R | LED2 | LED0603-RD |  | KT-0603R | KENTO | C2286 | LCSC
12 | 1 | XL-1615RGBC-RF | LED4 | LED-ARRAY-SMD_4P-L1.6-W1.5-BR_XL-1615RGBC-RF |  | XL-1615RGBC-RF | XINGLIGHT(成兴光) | C965840 | LCSC
13 | 1 | AO3401A | Q1 | SOT-23_L2.9-W1.3-P1.90-LS2.4-BR |  | AO3401A | AOS | C15127 | LCSC
14 | 2 | AO3400A | Q2,Q4 | SOT-23-3_L2.9-W1.3-P1.90-LS2.4-BR |  | AO3400A | AOS | C20917 | LCSC
15 | 1 | 2.2K | R1 | R0603 | 2.2K
16 | 10 | 10K | R2,R4,R8,R13,R14,R24,R27,R28,R33,R38 | R0603 | 10K
17 | 2 | 100K | R5,R6 | R0603 | 100K
18 | 2 | 680 | R7,R9 | R0603 | 680
19 | 4 | 5K1 | R10,R11,R25,R26 | R0603 | 5K1
20 | 5 | 33 | R17,R30,R31,R34,R37 | R0603 | 33
21 | 3 | 220 | R20,R22,R29 | R0603 | 220
22 | 1 | 100mΩ | R21 | R1206 | 100mΩ | RL12FTNR100 | 大毅科技 | C188071 | LCSC
23 | 1 | 10 | R23 | R0603 | 10
24 | 1 | 82 | R32 | R0603 | 82
25 | 1 | SK12D07VG4 | SW1 | SW-TH_SK12D07VG4 |  | SK12D07VG4 | SHOU HAN(首韩) | C393937 | LCSC
26 | 2 | TS-1102S-C-C-B | SW2,SW3 | KEY-SMD_4P-L6.0-W6.0-P4.50-LS8.6 |  | TS-1102S-C-C-B | XKB Connectivity(中国星坤) | C381039 | LCSC
27 | 1 | TS-1187A-B-A-B | SW4 | SW-SMD_4P-L5.1-W5.1-P3.70-LS6.5-TL_H1.5 |  | TS-1187A-B-A-B | XKB Connectivity(中国星坤) | C318884 | LCSC
28 | 1 | 2.4GHz | U1 | WIRELM-SMD_ESP32-S3-WROOM-1 | 2.4GHz | ESP32-S2-SOLO-2-N4 | ESPRESSIF(乐鑫) | C3040594 | LCSC
29 | 1 | TP4054-42-SOT25R | U2 | SOT-23-5_L3.0-W1.7-P0.95-LS2.8-BL |  | TP4054-42-SOT25R | TOPPOWER(南京拓微) | C32574 | LCSC
30 | 2 | pad_THT | U3,U4 | pad_THT
31 | 1 | Battery | U6 | lipo_battery
32 | 1 | XC6206P332MR-G | U7 | SOT-23-3_L2.9-W1.6-P1.90-LS2.8-BR |  | XC6206P332MR-G | TOREX(特瑞仕) | C5446 | LCSC
33 | 1 | S2B-PH-K(LF)(SN) | U8 | CONN-TH_S2B-PH-K-LF-SN |  | S2B-PH-K(LF)(SN) | JST | C265016 | LCSC
34 | 1 | YA13-FL7.4-B5Ka(45-10)-R-Y06 | U10 | RES-ADJ-TH_YA13-FL7.4-B5KA-45-10-R-Y06_1 |  | YA13-FL7.4-B5Ka(45-10)-R-Y06 | YTL(亚特联) | C37323742 | LCSC
35 | 1 | STK8321 | U13 | LGA-12_L2.0-W2.0-P0.50-TR |  | STK8321 | SENSORTEK(昇佳) | C966924 | LCSC
36 | 1 | INA199A1DCKR | U15 | SC-70-6_L2.2-W1.3-P0.65-LS2.1-BR |  | INA199A1DCKR | TI(德州仪器) | C59135 | LCSC
37 | 1 | ER-TFT018-3 | U16 | ER-TFT018-3
38 | 1 | HC-TYPE-C-16P-01A-L | USB1 | USB-C-SMD_G-SWITCH_GT-USB-7010EN |  | HC-TYPE-C-16P-01A-L | HCTL(华灿天禄) | C2997432 | LCSC

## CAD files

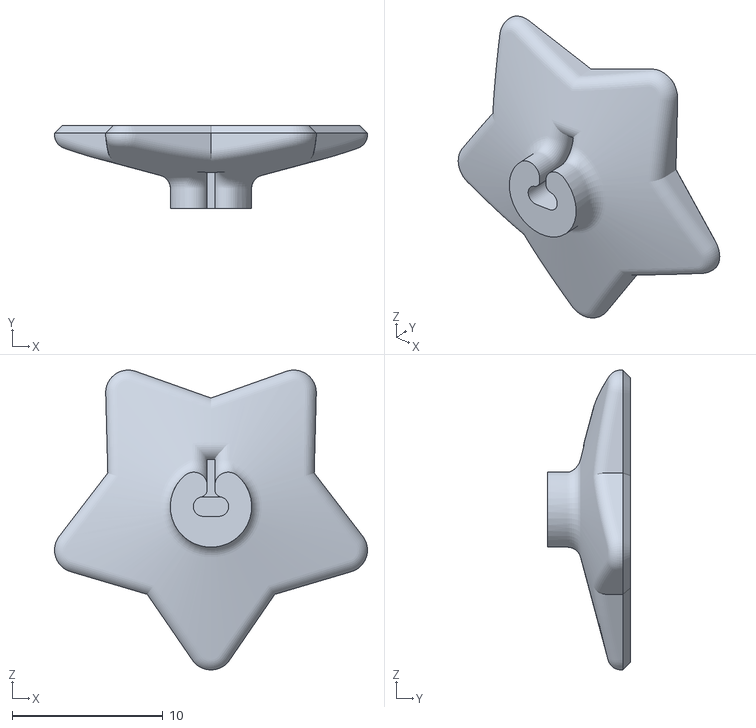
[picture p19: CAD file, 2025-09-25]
hardware/CAD/fall2025badge_joystick_final.STL
20.8 x 5.50 x 19.9

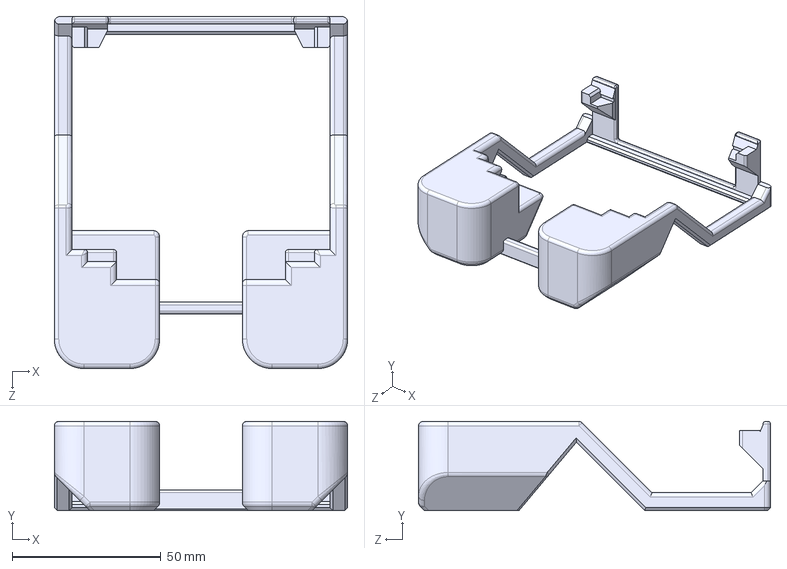
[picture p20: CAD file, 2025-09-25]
hardware/CAD/badge_case_final.STEP
98.8 x 30.0 x 118.5 mm

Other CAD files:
hardware/CAD/fall2025badge_joystick.STEP
hardware/CAD/badge_case_final.SLDPRT
hardware/CAD/badge_case_final.STL
hardware/CAD/fall2025badge_joystick.SLDPRT

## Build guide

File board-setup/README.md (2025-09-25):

# Build process

## Overview

The badge uses micropython. Micropython is a lightweight Python runtime for embedded systems. To use it, you must flash both the Micropython runtime itself along with the Python user code. Since the badge has a limited amount of RAM and loading Python source code from flash take significant memory, we decided to freeze the bulk of the code into the Micropython firmware binary. This frozen binary is in `firmware.bin` and it is built from files in `frozen_files` directory.

## Preliminaries

There are only two tools needed, `mpremote` and `esptool`. You can install both with pip (see requirements.txt). I recommend using a venv.

## Frozen files

To update the list of frozen files, use the sync file `frozen_files/sync_files.sh`.

To build the firmware, install [micropython](https://github.com/micropython/micropython) and ESP-IDF (see [guide](https://github.com/micropython/micropython/tree/master/ports/esp32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)).

We assume you have cloned micropython within the root of this repo. Then, `cd micropython/ports/esp32`. Source the idf.py if not done already. Then run the following command to build (the manifest path is relative to `micropython/ports/esp32/build-ESP32_GENERIC_S2/esp-idf/main_esp32s2/`).
```sh
make BOARD=ESP32_GENERIC_S2 FROZEN_MANIFEST=../../../../../../board-setup/frozen_files/manifest.py
cp build-ESP32_GENERIC_S2/firmware.bin ../../../board-setup
cd ../../../board-setup
python -m esptool --after no_reset write_flash 0x1000 firmware.bin
```

## Flashing

Run `./flash_firmware.sh` followed by `./flash_software.sh`. To put the board in bootloader mode, press the "B" button on the front while powering it up. The "B" button is the lower pushbutton when holding the board with the display on the top side.

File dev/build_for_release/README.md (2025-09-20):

# Fallctf 2025 Badge

This is the fallctf 2025 badge. It is written in Micropython, which is a subset of Python designed for microcontrollers.

In order to improve performance and reduce the memory usage, most of our code has been "frozen" into the micropython build. This means that it is packaged with the full micropython binary. To make hacking easier, a copy of the source code is provided here in the zip file. If you wish to make changes, simply make a copy of a file and move to the top level directory. For example, if you wanted to change settings.py (`import settings`), copy it from `src/settings.py` to the root and make changes there. Any changes will override code frozen in the binary.

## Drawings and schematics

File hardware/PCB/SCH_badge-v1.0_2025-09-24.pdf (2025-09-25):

# ESP32 Module

# Battery charging

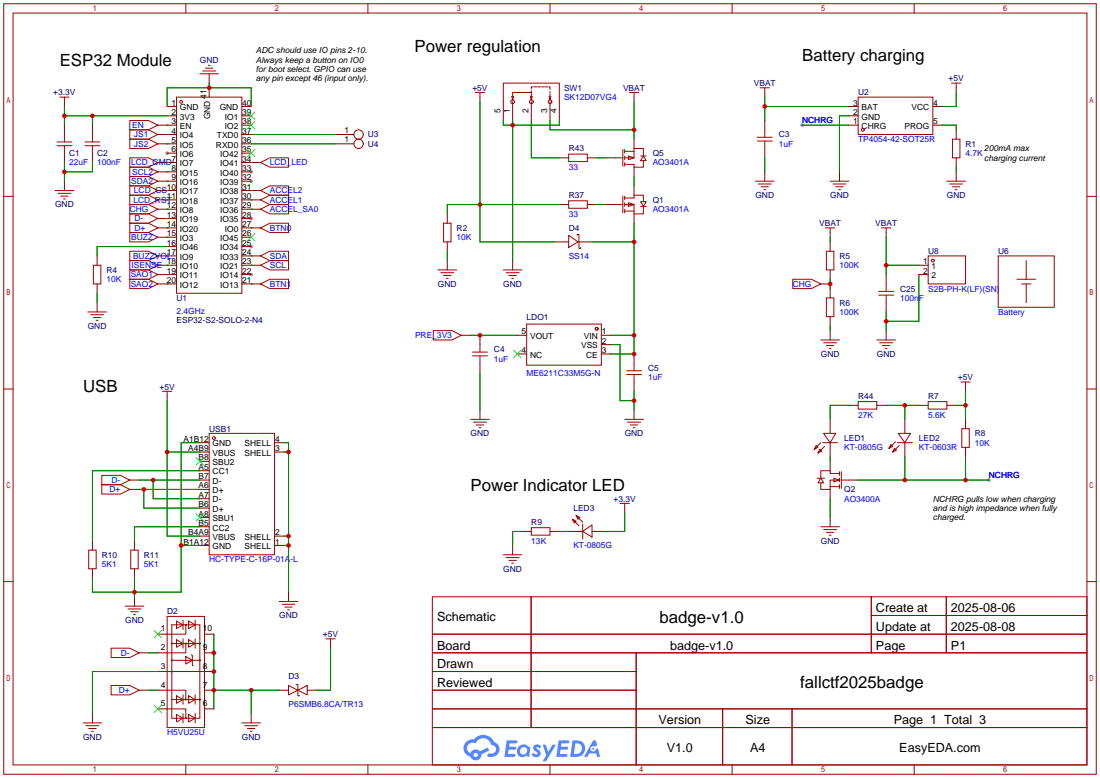
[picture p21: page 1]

ADC should use IO pins 2-10.
Always keep a button on IO0
for boot select. GPIO can use
any pin except 46 (input only).

NCHRG pulls low when charging
and is high impedance when fully
charged.

Schematic | badge-v1.0 | Create at | 2025-08-06

Update at | 2025-08-08

Board | badge-v1.0 | Page | P1
Drawn | | fallctf2025badge
Reviewed

Version | Size | Page 1 Total 3
V1.0 | A4 | EasyEDA.com

# Buttons

# Joystick

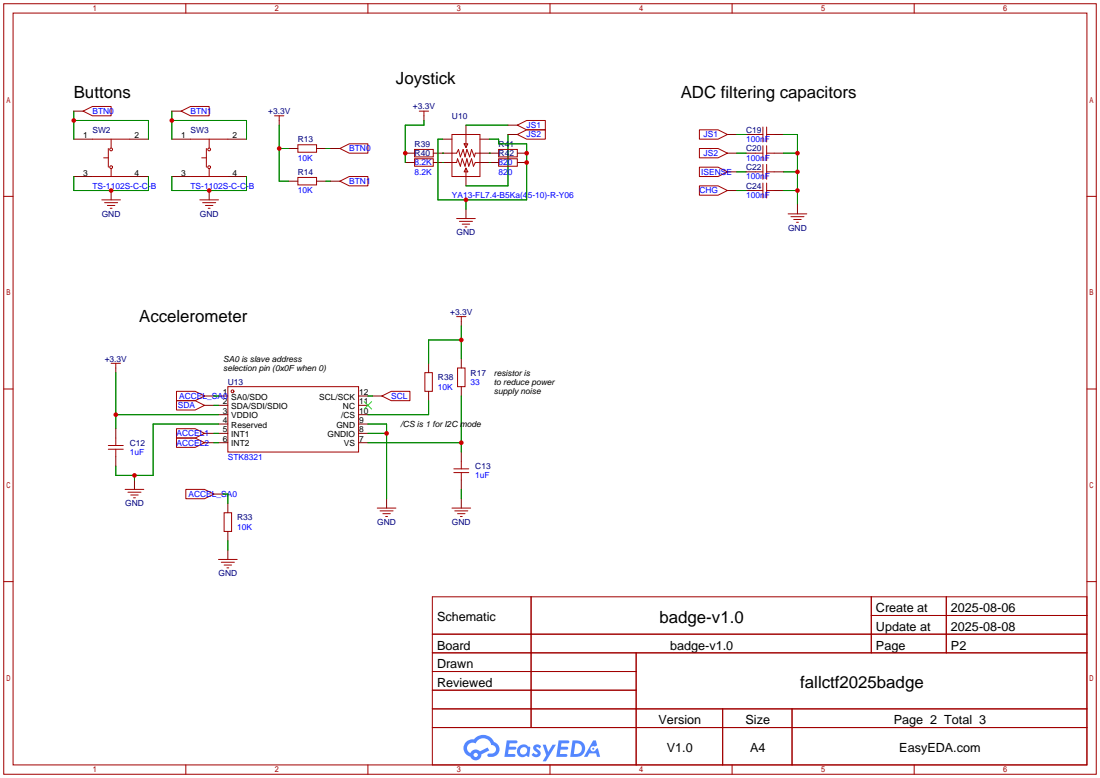
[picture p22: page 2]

/CS 10 NC 11 SCL/SCK 12

/CS is 1 for I2C mode

Schematic | badge-v1.0 | Create at | 2025-08-06

Update at | 2025-08-08

Board | badge-v1.0 | Page | P2
Drawn | | fallctf2025badge
Reviewed

# Current Sensing Buzzer

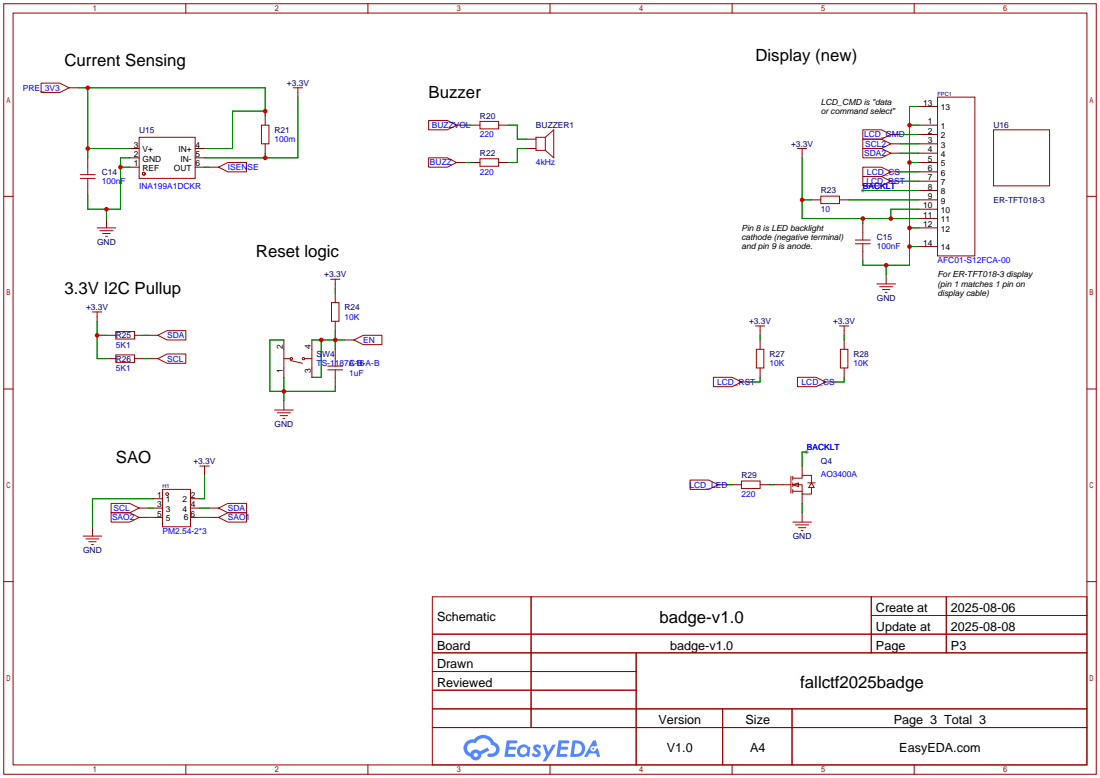
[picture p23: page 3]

Pin 8 is LED backlight
cathode (negative terminal)
and pin 9 is anode.

Schematic | badge-v1.0 | Create at | 2025-08-06

Update at | 2025-08-08

Board | badge-v1.0 | Page | P3
Drawn | | fallctf2025badge
Reviewed

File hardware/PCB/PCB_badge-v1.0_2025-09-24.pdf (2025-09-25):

# DISPLAY

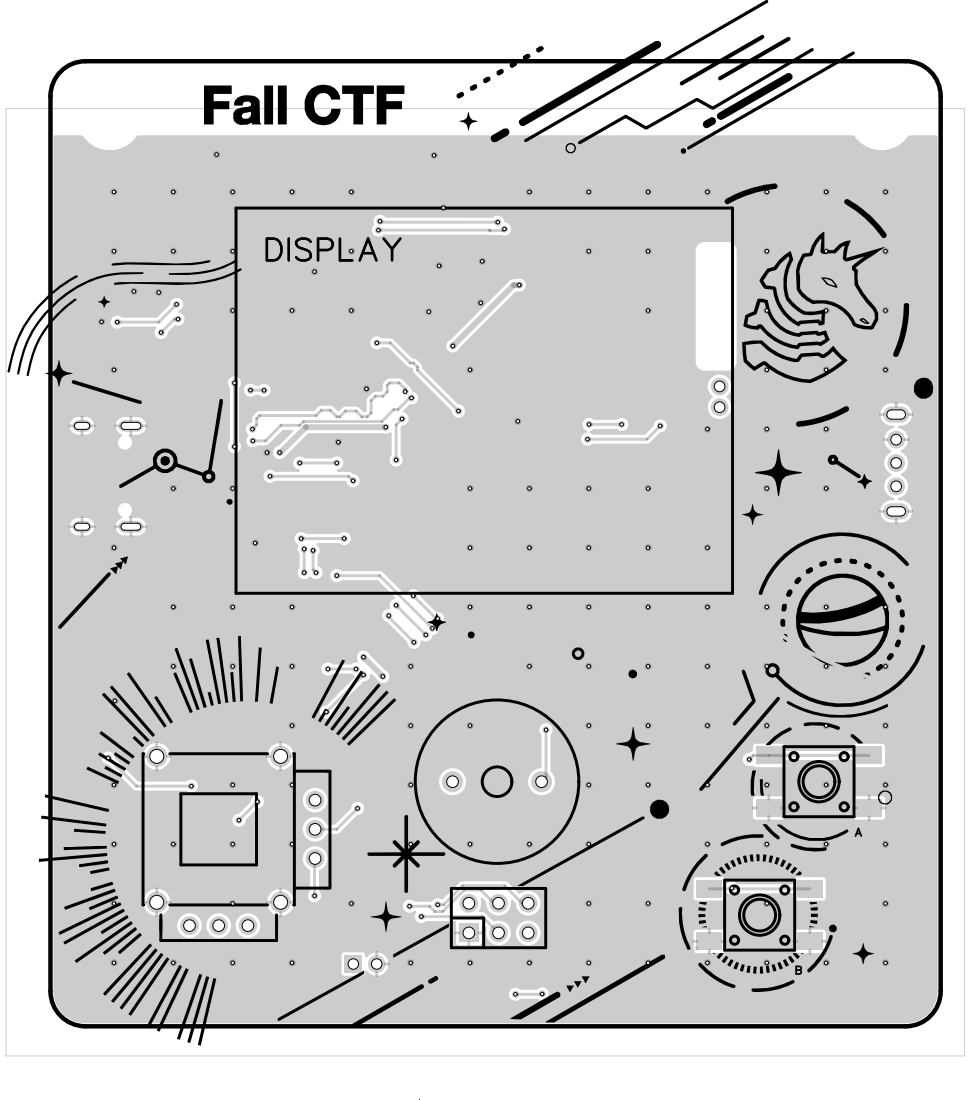
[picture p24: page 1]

R9

R17

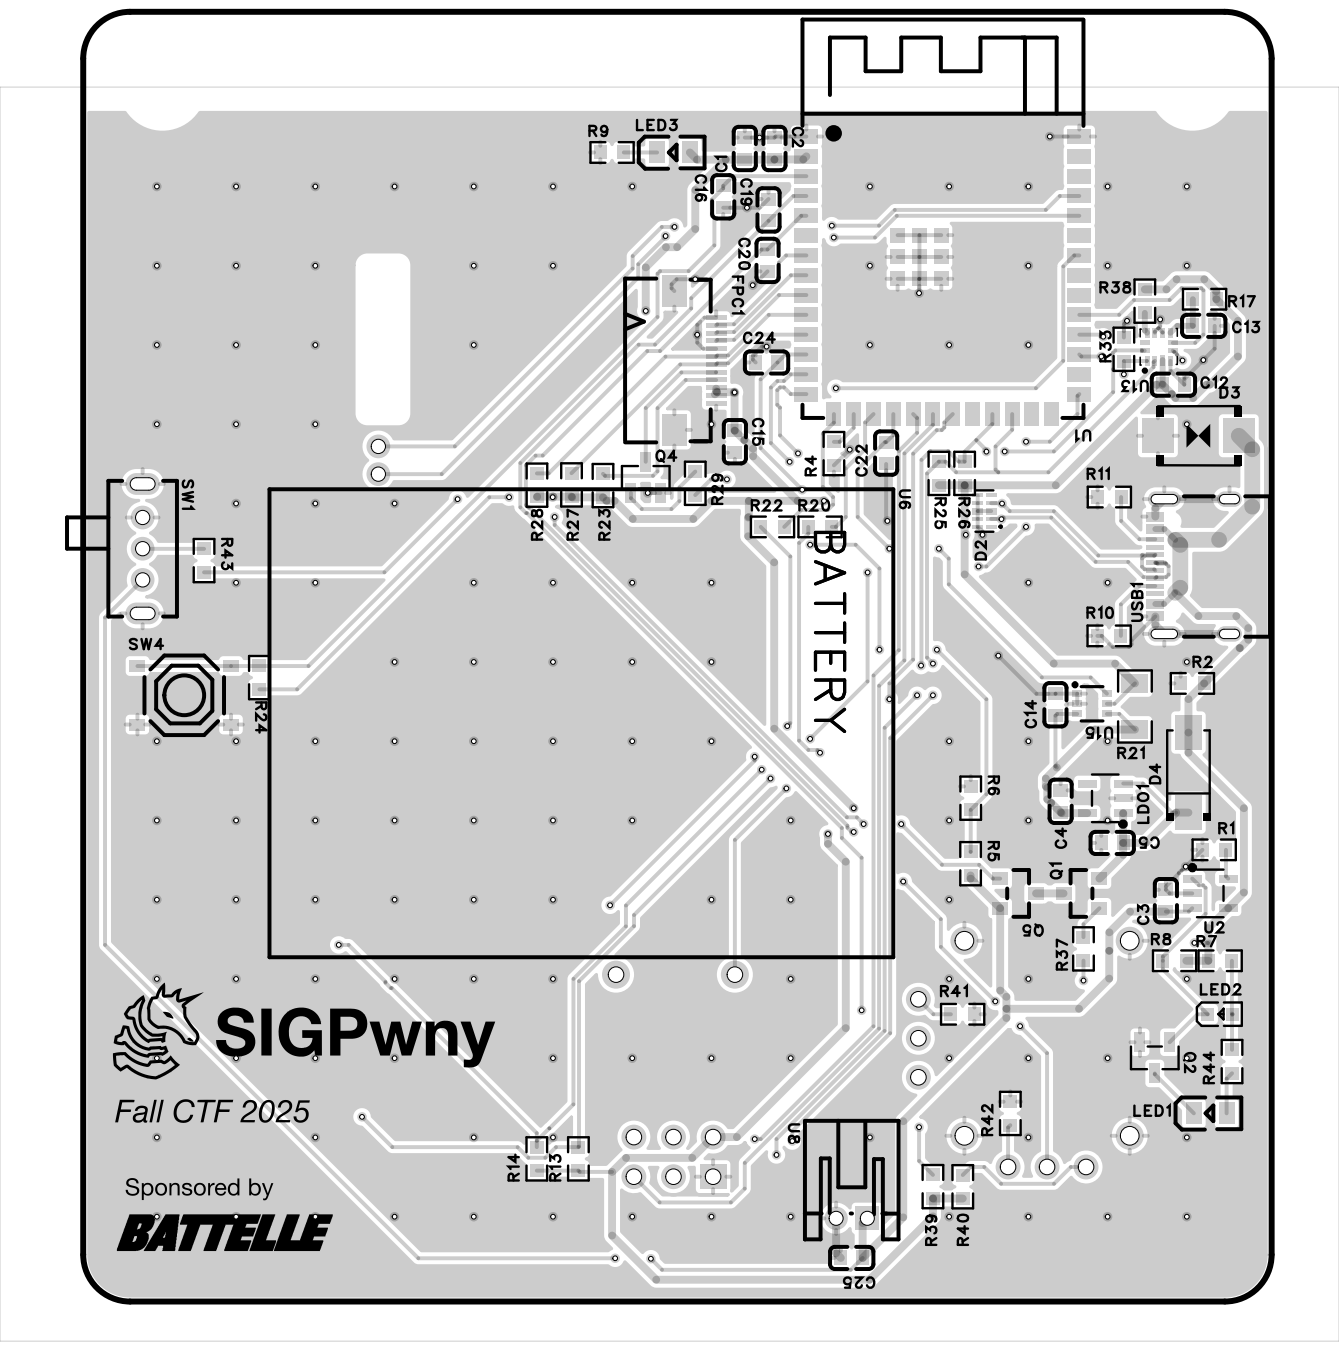
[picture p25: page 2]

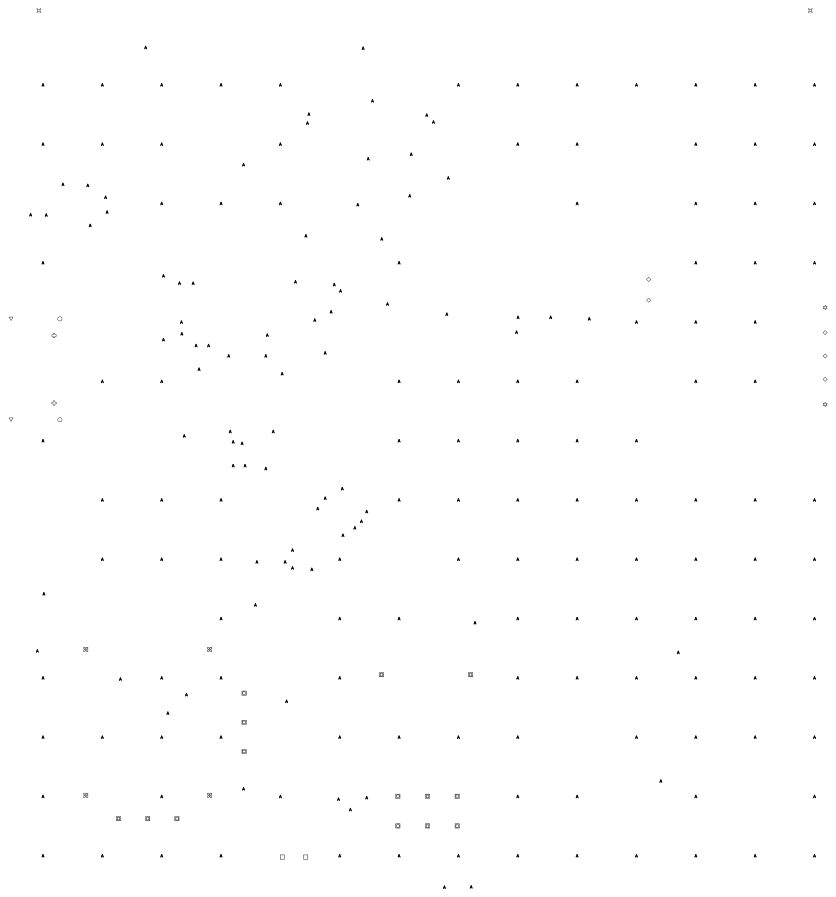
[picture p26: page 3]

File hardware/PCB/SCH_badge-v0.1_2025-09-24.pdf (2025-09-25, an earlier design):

# ESP32 Module

# Battery charging

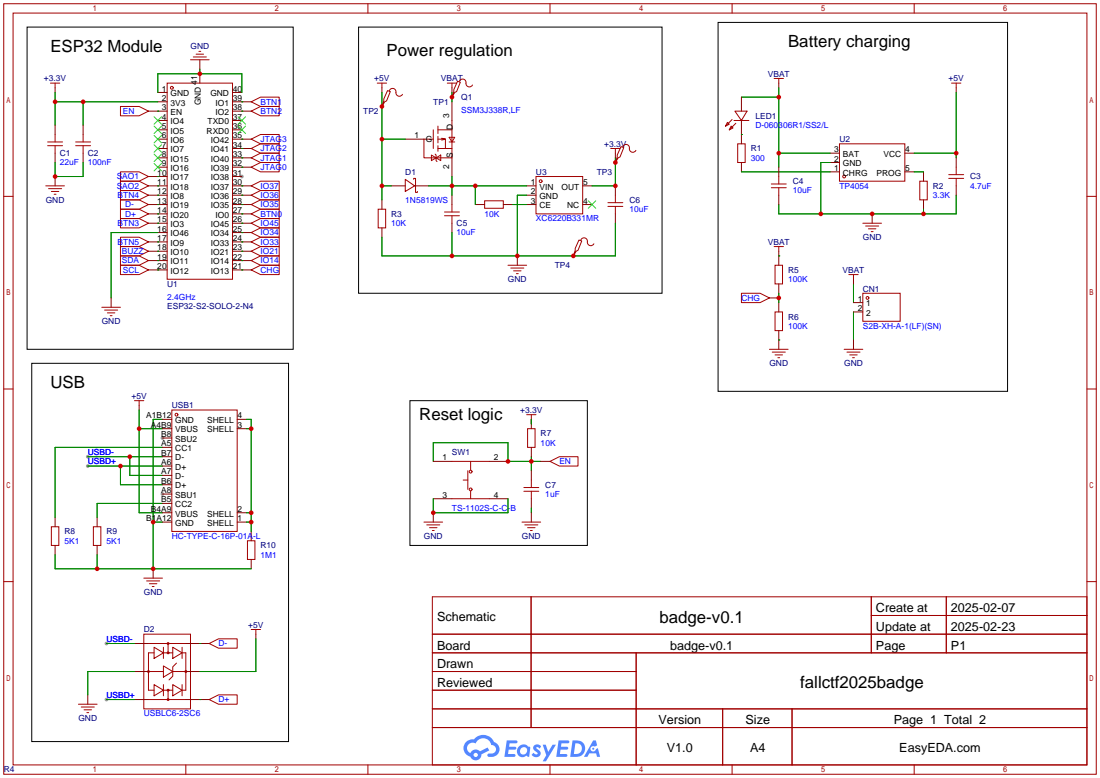
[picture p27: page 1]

Schematic | badge-v0.1 | Create at | 2025-02-07

Update at | 2025-02-23

Board | badge-v0.1 | Page | P1
Drawn | | fallctf2025badge
Reviewed

Version | Size | Page 1 Total 2
V1.0 | A4 | EasyEDA.com

Display | Buzzer

# SAO

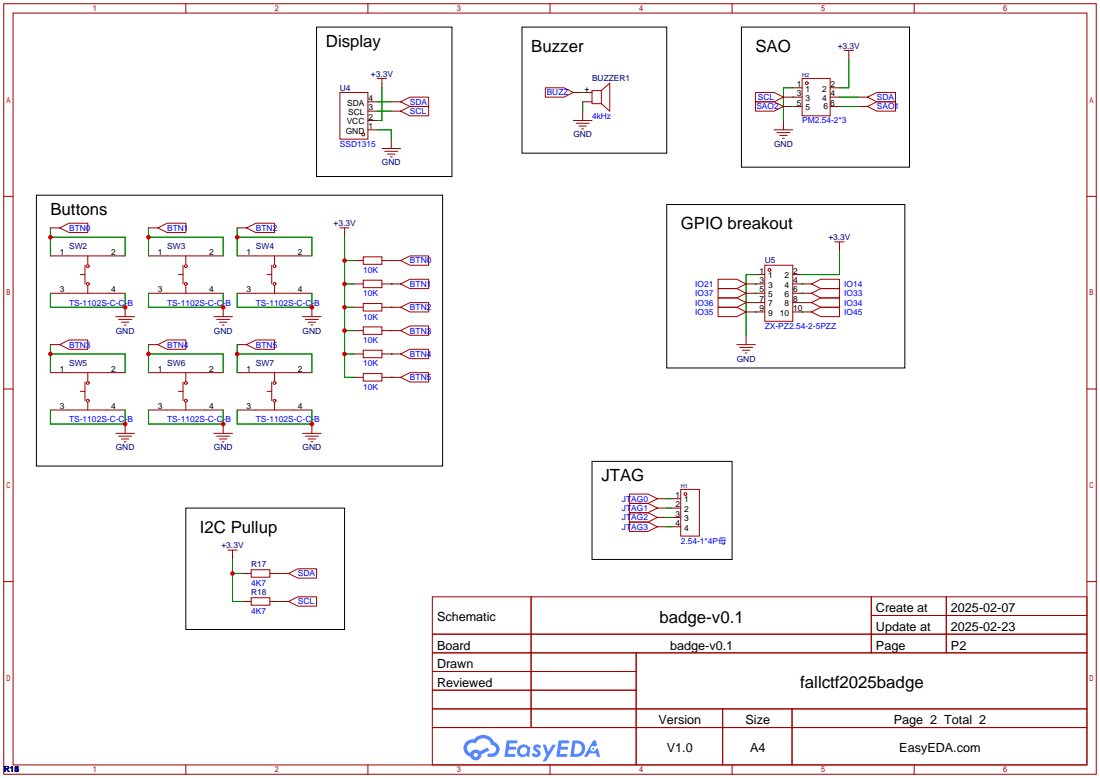
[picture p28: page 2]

Schematic | badge-v0.1 | Create at | 2025-02-07

Update at | 2025-02-23

Board | badge-v0.1 | Page | P2
Drawn | | fallctf2025badge
Reviewed

Version | Size | Page 2 Total 2
V1.0 | A4 | EasyEDA.com

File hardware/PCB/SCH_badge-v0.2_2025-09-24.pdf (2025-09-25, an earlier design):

# ESP32 Module

# Battery charging

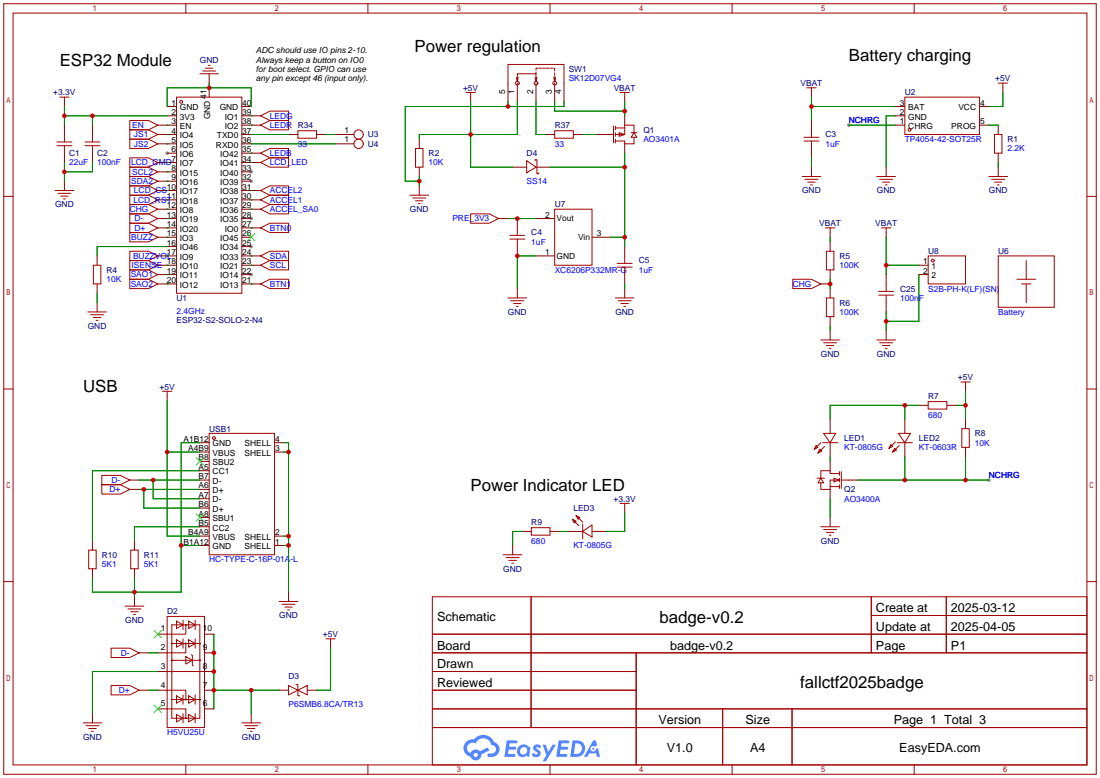
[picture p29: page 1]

ADC should use IO pins 2-10.
Always keep a button on IO0
for boot select. GPIO can use
any pin except 46 (input only).

Schematic | badge-v0.2 | Create at | 2025-03-12

Update at | 2025-04-05

Board | badge-v0.2 | Page | P1
Drawn | | fallctf2025badge
Reviewed

Version | Size | Page 1 Total 3
V1.0 | A4 | EasyEDA.com

# Buttons

# Joystick

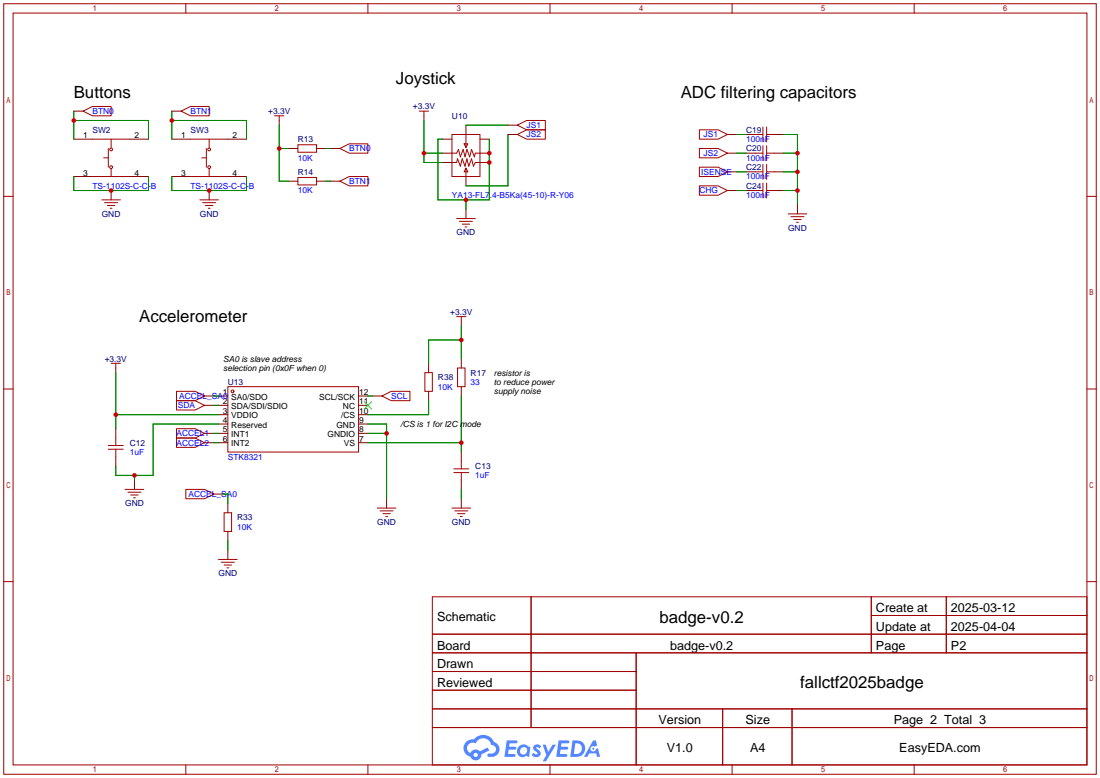
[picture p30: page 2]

/CS 10 NC 11 SCL/SCK 12

/CS is 1 for I2C mode

Schematic | badge-v0.2 | Create at | 2025-03-12

Update at | 2025-04-04

Board | badge-v0.2 | Page | P2
Drawn | | fallctf2025badge
Reviewed

# Current Sensing Buzzer

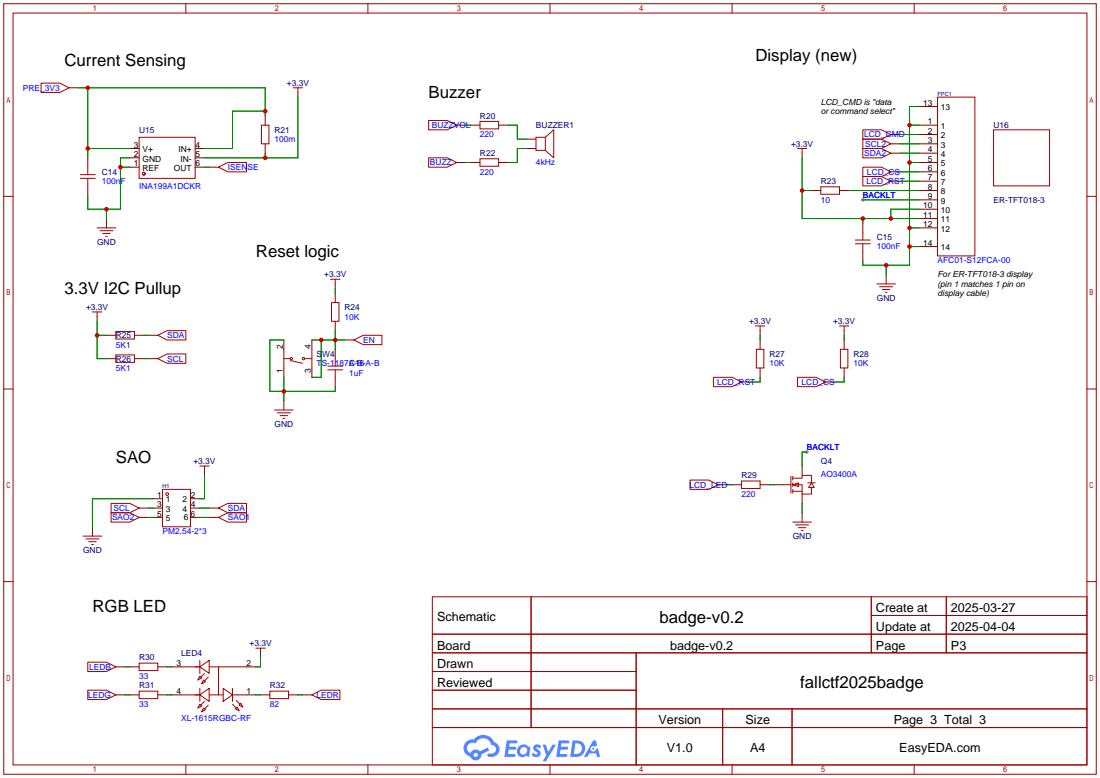
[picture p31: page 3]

Schematic | badge-v0.2 | Create at | 2025-03-27

Update at | 2025-04-04

Board | badge-v0.2 | Page | P3
Drawn | | fallctf2025badge
Reviewed

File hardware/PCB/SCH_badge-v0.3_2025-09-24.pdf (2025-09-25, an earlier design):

# ESP32 Module

# Battery charging

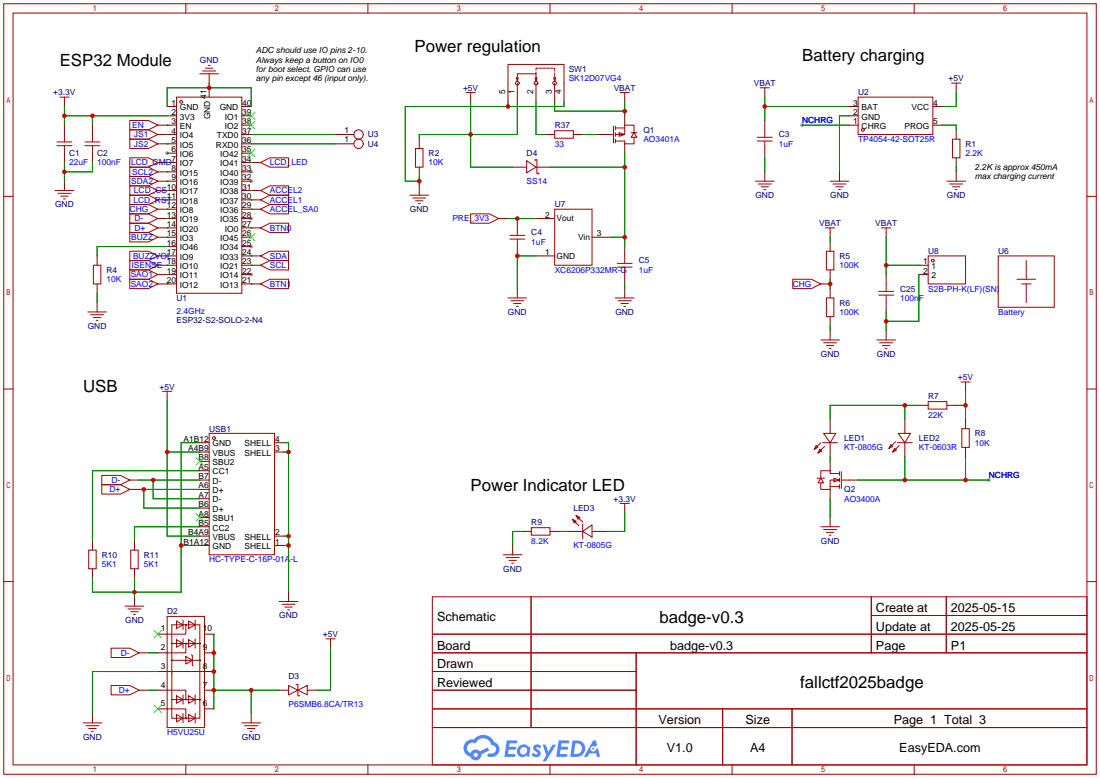
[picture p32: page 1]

ADC should use IO pins 2-10.
Always keep a button on IO0
for boot select. GPIO can use
any pin except 46 (input only).

Schematic | badge-v0.3 | Create at | 2025-05-15

Update at | 2025-05-25

Board | badge-v0.3 | Page | P1
Drawn | | fallctf2025badge
Reviewed

Version | Size | Page 1 Total 3
V1.0 | A4 | EasyEDA.com

# Buttons

# Joystick


/CS 10 NC 11 SCL/SCK 12

/CS is 1 for I2C mode

Schematic | badge-v0.3 | Create at | 2025-05-15

Update at | 2025-05-24

Board | badge-v0.3 | Page | P2
Drawn | | fallctf2025badge
Reviewed

# Current Sensing Buzzer


Pin 8 is LED backlight
cathode (negative terminal)
and pin 9 is anode.

Schematic | badge-v0.3 | Create at | 2025-05-15

Update at | 2025-05-25

Board | badge-v0.3 | Page | P3
Drawn | | fallctf2025badge
Reviewed




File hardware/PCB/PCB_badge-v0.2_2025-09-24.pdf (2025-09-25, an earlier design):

# DISPLAY




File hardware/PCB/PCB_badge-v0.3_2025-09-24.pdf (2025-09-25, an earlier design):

# DISPLAY




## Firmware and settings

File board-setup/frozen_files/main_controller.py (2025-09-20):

from view import BasicTextView
from menu import ListMenu, HomeMenu, menu_with_text
from layout import Style
import wireless
from connect import ConnectMenu
from upgrade import UpgradeMenu
from settings import SettingsMenu
from more import MoreMenu
from intro_screen import IntroScreen

from logger import log

TYPE_CHECKING = False
if TYPE_CHECKING:
    from device_io import DeviceIO


class MainController:
    def __init__(self, device_io: "DeviceIO"):
        self.device_io = device_io

    async def run(self):
        log('MainController started')
        if self.device_io.ship_stats.show_intro:
            await IntroScreen(self.device_io).run()
        self.device_io.ship_stats.show_intro = 0
        self.device_io.ship_stats.save()

        print('fallctf{s1gpwny_m4k3s_h4rdwar3!}')

        log('MainController main loop')
        while True:
            await HomeMenu(
                self.device_io,
                [
                    ConnectMenu(self.device_io),
                    UpgradeMenu(self.device_io),
                    MoreMenu(self.device_io),
                    SettingsMenu(self.device_io),
                ]
            ).run()

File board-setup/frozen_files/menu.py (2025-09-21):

import asyncio
import framebuf

from microfont import MicroFont
from view import BasicTextView, global_buffer
from layout import ComplexLayout, Style
from logger import log


TYPE_CHECKING = False
if TYPE_CHECKING:
    from typing import Callable
    from device_io import DeviceIO
    MenuItem = tuple[str, list['MenuItem'] | None, 'Runnable' | Callable[[], 'Runnable | None'] | None]


class Runnable:
    async def run(self):
        pass


class ListMenu(Runnable):
    def __init__(
        self,
        device_io: "DeviceIO",
        items: list['MenuItem'],
        init_selected: int = 0,
        *,
        additional_views=None,
        prepended_views=None,
        cancel_event=None,
        exit_on_b_handler=None,
        enable_render_cache=False,
    ):
        self.device_io = device_io
        self.sub_idx_ranges = []
        # cannot have 0 items
        items = items or [("no items", None, None)]
        self.actions: list[Callable[[], Runnable] | None] = []
        self.view = ComplexLayout(device_io.display, enable_render_cache=enable_render_cache)
        if prepended_views is not None:
            for v, s in prepended_views:
                self.view.append((v, s))
        for name, sub, action in items:
            self.view.append(
                (
                    BasicTextView(device_io.display),
                    Style(posType=0b01, y=5),
                )
            )
            self.view[-1][0].update(0, "  " + name)
            self.actions.append(action)

            if sub is not None:
                st = len(self.view)
                for subname, _, action in sub:
                    # ignore submenu for submenus for now
                    self.view.append(
                        (
                            BasicTextView(device_io.display),
                            Style(posType=0b01, x=20, y=5, hidden=True),
                        )
                    )
                    self.view[-1][0].update(0, "  " + subname)
                    self.actions.append(action)
                self.sub_idx_ranges.append((st, len(self.view)))
        self.menu_start = len(prepended_views) if prepended_views else 0
        self.menu_end = len(self.view)

        if additional_views is not None:
            for v, s in additional_views:
                self.view.append((v, s))

        self.keep_running = True
        self.item_selected = False
        self.last_select = init_selected + self.menu_start
        self.select_idx = init_selected + self.menu_start
        self._wrap_select_idx()

        first_selected_view = self.view[self.select_idx][0]
        first_selected_view.update(0, ">" + first_selected_view.lines[0][1:])

        self.cancel_event = cancel_event
        self.exit_on_b_handler = exit_on_b_handler
        self.controls_on = True

    def _wrap_select_idx(self):
        self.select_idx = (self.select_idx - self.menu_start) % (self.menu_end - self.menu_start) + self.menu_start

    def joystick_event(self, event_type, value):
        if not self.controls_on:
            return
        if event_type == "up-down":
            if value:
                self.select_idx -= 1
            else:
                self.select_idx += 1
            self._wrap_select_idx()


    def button_event(self, button, pressed):
        if not pressed or not self.controls_on:
            return
        if button == 'a':
            if self.actions[self.select_idx - self.menu_start] is not None:
                self.keep_running = False
                self.item_selected = True
                return
            for st, end in self.sub_idx_ranges:
                if st == self.select_idx + 1:
                    # in a submenu
                    # toggle visibility of submenu
                    for i in range(st, end):
                        self.view[i][1].hidden = not self.view[i][1].hidden
                    self.view[self.select_idx][0].update(
                        0,
                        (">" if self.view[st][1].hidden else "V")
                        + self.view[self.select_idx][0].lines[0][1:],
                    )
        elif button == 'b':
            for st, end in self.sub_idx_ranges:
                if st <= self.select_idx < end:
                    # in a submenu
                    # toggle visibility of submenu
                    for i in range(st, end):
                        self.view[i][1].hidden = True
                    self.select_idx = st - 1
                    return
            if self.exit_on_b_handler is not None:
                self.keep_running = False
                self.exit_on_b_handler()

    async def run(self):
        self.device_io.joystick.subscribe(self.joystick_event, events=["up-down"])
        self.device_io.buttons.subscribe(self.button_event, events=["a", "b"])
        self.view.first_render()

        while self.keep_running:
            if self.last_select != self.select_idx:
                self.view[self.last_select][0].update(
                    0, " " + self.view[self.last_select][0].lines[0][1:]
                )
                self.view[self.select_idx][0].update(
                    0, ">" + self.view[self.select_idx][0].lines[0][1:]
                )
                self.last_select = self.select_idx
            self.view.render()
            await asyncio.sleep_ms(20)
            if self.cancel_event is not None and self.cancel_event.is_set():
                self.keep_running = False
        if self.item_selected:
            action = self.actions[self.select_idx - self.menu_start]
            if action is not None:
                self.controls_on = False
                if isinstance(action, Runnable):
                    await action.run()
                elif callable(action):
                    result = action()
                    # await if it's a coroutine
                    if hasattr(result, '__await__'):
                        await result
                elif hasattr(action, '__await__'):
                    await action
                else:
                    raise ValueError("Action is neither Runnable nor callable nor awaitable")
                self.controls_on = True

        self.device_io.joystick.unsubscribe(self.joystick_event, events=["up-down"])
        self.device_io.buttons.unsubscribe(self.button_event, events=["a", "b"])
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

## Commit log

2025-04-28 add esp32s2 code
2025-04-29 test accelerometer
2025-05-06 Created display interface, fixed noise
    [ST7735.py, display.py]
2025-05-07 add accelerometer screen
2025-05-07 Updated noise values, reformatted display interface
    [display.py]
2025-05-13 fix accelerometer
2025-08-08 working espnow with lower transmit power
2025-08-31 feat: support print with font and add boot screen
2025-08-31 chore: fix color palette issue, add type hint
    [boolpalette.py, boot_screen.py, display.py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]
2025-09-02 fix ptr16 not found in microfont
    [microfont.py]
2025-09-02 add buttons
2025-09-06 fix joystick events not triggering mutliple times (e.g. moving down twice)
    [joystick.py]
2025-09-06 add accelerometer
2025-09-06 move peripherals to a container class so we don't need to pass them as parameters each time (joystick, buttons, accelerometer, display, ship_stats)
2025-09-06 add battery and power monitoring
2025-09-06 disable espnow at startup to save power
2025-09-06 uncomment accelerometer whoops
2025-09-07 chore: use ColumnLayout replace Col layout
    [boot_screen.py, layout.py, view.py]
2025-09-09 fix some type checking stuff
    [device_io.py, layout.py, menu.py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]
2025-09-09 move menu button processing back to the event handler this avoids the fold toggling issue
    [menu.py]
2025-09-11 add wireless test
2025-09-14 finish wireless battle
2025-09-14 fix display color issue
    [ST7735.py, main_controller.py]
2025-09-14 fix battle ship side
    [connect.py]
2025-09-14 change undo button to cancel
2025-09-17 chore: support B button back in first level of connect and setting menu
2025-09-17 fix back button in connect menu
    [connect.py]
2025-09-17 fix: fix exit on b of connect and setting menu
    [connect.py, menu.py, settings.py]
2025-09-18 fix: fix b exit on upgrade menu
    [menu.py, upgrade.py]
2025-09-18 fix: fix control issue in listmenu
    [menu.py]
2025-09-19 asteroids game: improvements
    - stats affect ship movement
    - add timer
    - change diminishing returns when getting stardust from repeated
    connections
2025-09-19 start making asteroids game multiplayer
    - the lag is terrible currently
2025-09-19 asteroids game: draw other player correctly
    - avoid joystick drift by making center values 0
    - use 4-digit numeric connection code
    [asteroids_game.py, joystick.py, wireless.py]
2025-09-20 asteroids game: fix lag issues
    [asteroids_game.py, settings.py, ship_stats.py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]
2025-09-20 chore: minor fix in upgrade menu
    [upgrade.py]
2025-09-20 minor fixes and move assets around
    [asteroids_game.py, speaker.py]
2025-09-21 fix upgrade joystick drift
    [upgrade.py]
2025-09-21 fix upgrades costing the wrong amount of stardust
    [ship_stats.py]
2025-09-21 fix: wrap bitMap to try to fix memory leak
    [boot_screen.py, upgrade.py, view.py]
2025-09-21 fix: ignore set changed in hook
    [view.py]
2025-09-21 fix memory leak in upgrade
    [invaders_game.py, menu.py, upgrade.py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]
2025-09-21 remove board reset stuff since that causes bulk script to be confused
2025-09-21 fix: fix the basicText change
    [view.py]
2025-09-21 fix: fix shake color by changing back color in last tick
    [view.py]
2025-09-21 fix timeout, add power view
    [settings.py, wireless.py]
2025-09-25 add hardware docs
    [BOM_badge-v0.1_badge-v0.1_2025-09-24.csv, BOM_badge-v0.2_badge-v0.2_2025-09-24.csv, BOM_badge-v0.3_badge-v0.3_2025-09-24.csv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]
2025-09-25 add hardware modeling files
    [BOM_badge-v0.1_badge-v0.1_2025-09-24.csv, BOM_badge-v0.2_badge-v0.2_2025-09-24.csv, BOM_badge-v0.3_badge-v0.3_2025-09-24.csv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]
